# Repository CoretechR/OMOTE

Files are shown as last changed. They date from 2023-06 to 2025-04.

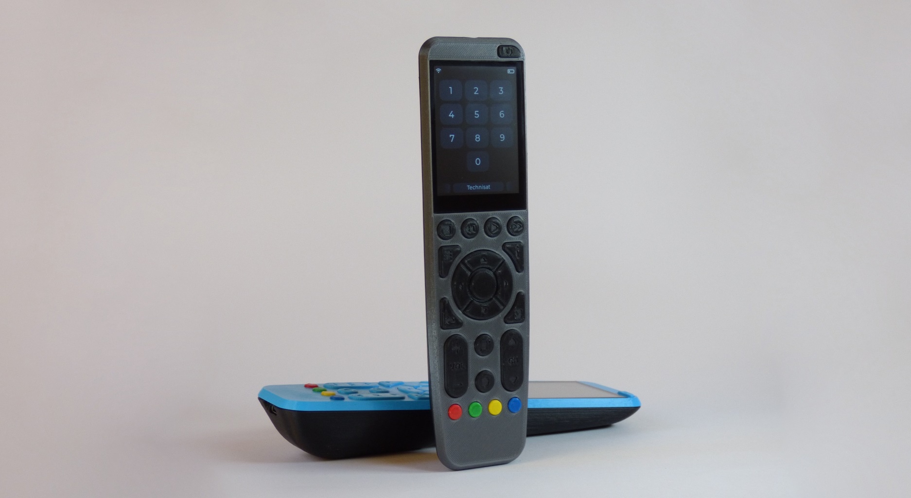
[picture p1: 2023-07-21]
images/OMOTE_assembled.jpg

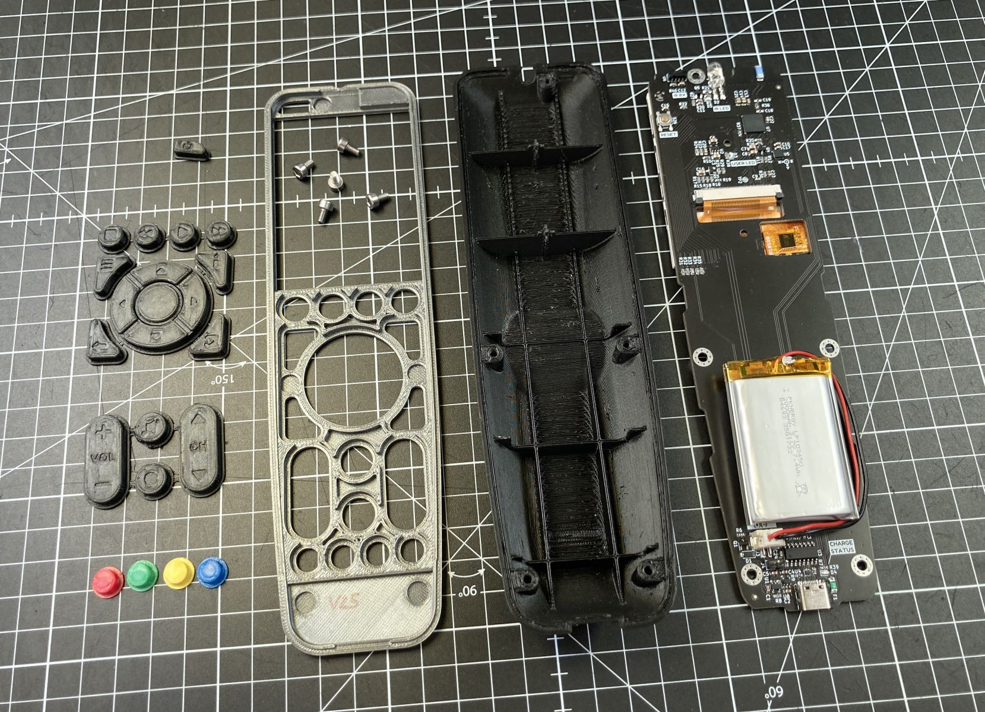
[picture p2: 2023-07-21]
images/OMOTE_parts.jpg

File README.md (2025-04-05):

# OMOTE - Open Universal Remote - Firmware




[OMOTE Discord][link1]

## Overview

This it the ESP32 arduino based firmware for the OMOTE - Open Universal Remote.

To run this firmware, you have two options
*  run it on the [OMOTE ESP32 Hardware](https://github.com/OMOTE-Community/OMOTE-Hardware/)
*  run it in the simulator on Linux, macOs or Windows

### The state of this project

The software can be adjusted to your needs. You can add your own amplifier, TV and media player. Smart home devices can be controlled with MQTT. The software is an example made up of:
* a TV and an amplifier controlled with infrared
* a Fire TV media player controlled with BLE (bluetooth keyboard)
* some smart home devices controlled with MQTT
* an IR receiver for decoding the IR codes from your remote

Please see the [wiki on how to understand and modify the firmware.](https://github.com/OMOTE-Community/OMOTE-Firmware/wiki/How-to-understand-and-modify-the-firmware)

You need to have PlatformIO running, and you need to know how to compile and flash your own firmware with PlatformIO. There is no prebuild firmware.

The remote can be charged and programmed via its USB-C port. Open the PlatformIO project to compile and upload the code to the ESP32.

As a long term goal, maybe a prebuild firmware will be published, where you can configure your OMOTE via a web interface.

### LVGL GUI simulator for Windows, Linux, and macOS

A simulator for running the LVGL UI on your local Windows, Linux, or macOS machine is available.

You can run the simulator in Visual Studio Code with PlatformIO. No need for any other compiler or development environment (no Visual Studio needed as often done in other LVGL simulators).
<div align="center">
  
</div>

For details, please see the [wiki for the software simulator for fast creating and testing of LVGL GUIs.](https://github.com/OMOTE-Community/OMOTE-Firmware/wiki/Software-simulator-for-fast-creating-and-testing-of-LVGL-GUIs)

### To Dos for software

Long term goals (not yet scheduled)
- [ ] Add an interface for graphically editing the configuration
- [ ] Store the configuration in Flash (e.g. as a editable json file)

See the [open issues](https://github.com/OMOTE-Community/OMOTE-Firmware/issues) and [discussions](https://github.com/OMOTE-Community/OMOTE-Firmware/discussions) for a full list of proposed features (and known issues).

## Contributing

If you have a suggestion for an improvement, please fork the repo and create a pull request. You can also simply open an issue or for more general feature requests, head over to the [discussions](https://github.com/OMOTE-Community/OMOTE-Firmware/discussions).

## License

Distributed under the GPL v3 License. See [LICENSE](https://github.com/OMOTE-Community/OMOTE-Firmware/blob/main/LICENSE) for more information.

## Contact

[OMOTE Discord][link1]

Join the OMOTE Discord: [https://discord.gg/5PnYFAsKsG](https://discord.gg/5PnYFAsKsG)

[link1]: https://discord.gg/5PnYFAsKsG

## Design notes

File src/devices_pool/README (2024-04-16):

This directory is intended for a pool of devices already contributed by the community of OMOTE.
Files in this directory won't get compiled by default.

If you want to use one of these devices, then
- copy the corresponding device folder from "/src/devices_pool/..." to "/src/devices/..."
- add the corresponding call to "register_device_*()" into "/src/main.cpp" (and include the device header file in "/src/main.cpp" as well)
- start using the commands defined by the device, e.g. by putting them in the hardware key map of "scene__default.cpp" or of a specific scene

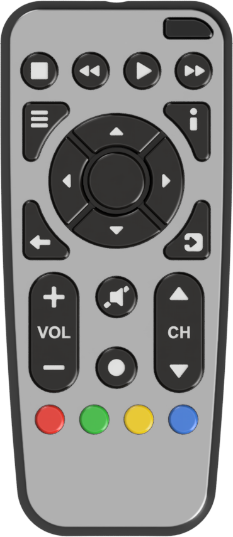
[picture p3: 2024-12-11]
hardware/windows_linux/keypad_gui/buttons.png

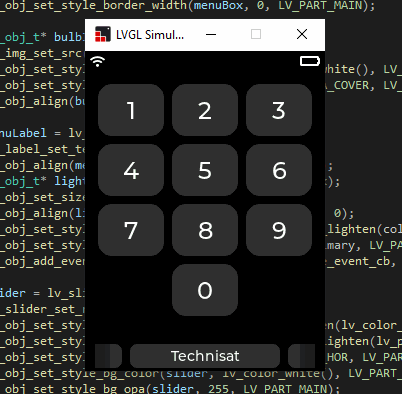
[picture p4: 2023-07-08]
images/sim GIF.gif

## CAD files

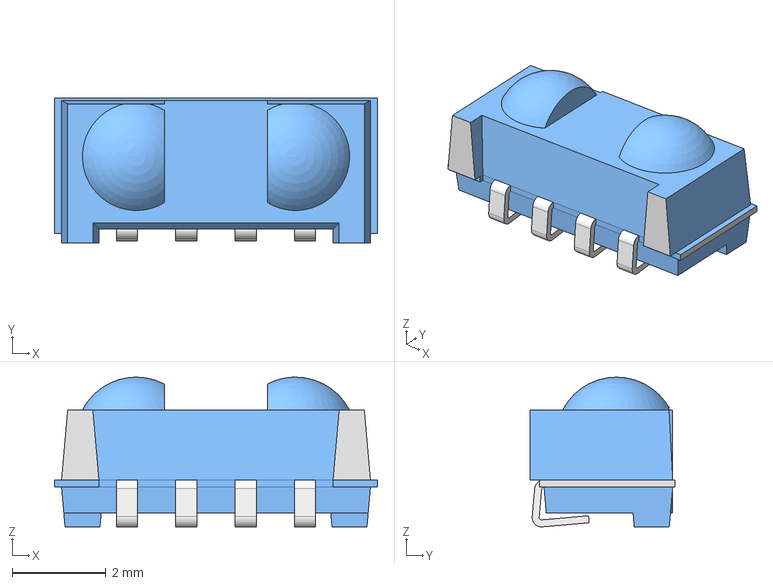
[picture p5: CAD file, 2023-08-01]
PCB/project_libraries/3D-models/82672Heimdall.stp
6.90 x 3.10 x 3.20 mm

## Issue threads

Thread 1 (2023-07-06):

Add gerber files

thijstriemstra, 2023-07-06:
Would be great to have the gerber/bom/placement files so it can be produced by a company like JLPCB or PCBWay.

I tried exporting it from Kicad 7 but there are so many options, not sure what to do, I'm new to this.

CoretechR, 2023-07-06:
Hi, you're right, I will add those files to the repository soon.
Until then there are plugins for both JLCPCB and PCBWay in KiCad that work really well.

mandreko, 2023-07-07:
I just generated these in KiCad in a way that has worked for me for previous PCBs, if it's helpful.

[OMOTE_gerber_20230707.zip](https://github.com/CoretechR/OMOTE/files/11985526/OMOTE_gerber_20230707.zip)

thijstriemstra, 2023-07-07:
thanks @mandreko. I believe we'll also need the bom and placement csv files for jlpcb (?).

CoretechR, 2023-07-08:
Added the GERBER files (7b5d897)
These were exported by the JLCPCB plugin, but should work for other manufacturers as well.

Closed 2023-07-08.

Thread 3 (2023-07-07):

BOM and sourcing components

mandreko, 2023-07-07:
Firstly, I love this project. Not just from it's sole purpose, but also for someone trying to learn electronic engineering better. I am studying the PCB to try to figure out how everything was done and the purpose of each yet.

I figured I'd start to build at least one of these. I created a BOM here: https://octopart.com/bom-tool/xXZMKVQA

The issues I have thus far, are:

1. Making sure everything on that BOM is correct.
2. Sourcing specific components that seem to be obsolete or not readily available.

Can you check that this BOM is correct, or supply one separately, to address issue 1?

For 2, I'm finding that SFH4346 is considered "obsolete" and not readily available anywhere that I can find. I think that SFH4546 might be a replacement, but I'm unsure. Additionally, trying to source the CH340C is tough as far as I can tell outside of LCSC. Is that where you got yours, or did you find it (or an alternative) elsewhere?

Thanks!

thenicnet, 2023-07-07:
Just a heads up, the **MIKROE-1120** is US Only from Mouser and DigiKey.
Anyone outside the US might have to source a comparable battery.

mandreko, 2023-07-08:
That's definitely a good note. I didn't specifically look for availability per country, but it's likely wise. I imagine there's a similar battery for other countries, but we may have to search for it some more.

CoretechR, 2023-07-08:
Hi @mandreko , I've added a BOM to the project now:
https://github.com/CoretechR/OMOTE/blob/main/PCB/BOM.csv
These are the parts that I ordered when I built the remote. Maybe you can check that against your list.
The IR LED should not be an issue. You can probably use any 3mm IR LED.

retorquere, 2023-07-09:
If anyone in Europe is looking to sell an assembled one, I'm interested.

syntaxerr66, 2023-07-12:
For those trying to source the CH340C, I just ordered some from this aliexpress vendor. Fingers crossed they're legit and work, but it was only $8 total, so it's worth a shot.

https://www.aliexpress.us/item/3256804957277020.html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

bjoerns1983, 2023-07-13:
If anyone would sell assembled PCB's i would be interested. 3D Printing is not a problem.
Love the Idea of an remote you could also use for MQTT!

moserja, 2023-07-14:
Did R1,R38,R39,R40 get removed? I don't see them in the BOM.csv file.

CoretechR, 2023-07-15:
> Did R1,R38,R39,R40 get removed? I don't see them in the BOM.csv file.

Good that you noticed, R37 was missing as well. Should be fixed now.

dekiesel, 2023-07-15:
Is there any way to subscribe to see when somebody decided to sell a ready made pcb (in the EU)? I'd love to have one of those, but my attempts at smt soldering have been very fruitless so far.

CoretechR, 2023-07-15:
@dekiesel If something comes up, I will definitely post it on Hackaday.io and Twitter.

JediMongoose, 2023-07-16:
I'd also be very interested in buying an assembled PCB.. had a look on tindie.com, but nothing yet :)

mandreko, 2023-07-16:
@JediMongoose Give it a couple weeks, and there likely will. I’ll be at least buying components for enough boards to put up there in small quantities.

JediMongoose, 2023-07-16:
> @JediMongoose Give it a couple weeks, and there likely will. I’ll be at least buying components for enough boards to put up there in small quantities. (US based)

I ended up here due to the hackaday feature (https://hackaday.com/2023/07/15/hackaday-prize-2023-omote-universal-remote/) - I'm sure there'll be more :smile:

hypercube33, 2023-07-18:
I'm doing a struggle to see if I can get PCB's made and see how impossible this is to solder myself. I've never done more than through-hole so this should be interesting. I have an immediate need for at least 2 of these, ideally expanding them with a hub when that is finalized. Also would love to help in any way! My life is a void now that Logi dropped Harmony.

mandreko, 2023-07-18:
If it’s helpful, I’ve purchased the PCBs and components for about 10x remotes. Once they come in, I’m more than happy to build some for others. I enjoy soldering.

ramonflores08, 2023-07-18:
I would do the same but don't have the funds to buy so many 😕

Dark1886, 2023-07-20:
I will also have a few boards that I will have left over, but they will not have the screen or battery installed. Those are easy additions though.

ramonflores08, 2023-07-20:
I will have 4 pcbs left over from the batch I ordered.if someone wants one and is willing to buy the components I can solder them.

Wolverine-14, 2023-07-21:
> I will have 4 pcbs left over from the batch I ordered. if someone wants one and is willing to buy the components I can solder them.

I would be interested.

tnph, 2023-07-24:
> If it’s helpful, I’ve purchased the PCBs and components for about 10x remotes. Once they come in, I’m more than happy to build some for others. I enjoy soldering.

I'm interested in buying a populated PCB, and willing to pay in advance if required

dekiesel, 2023-07-24:
It would be helpful if the people that are offering to help others would say where they are located.

GaryTill, 2023-07-24:
I'm also in Australia if anyone is selling partially or fully assembled PCBs.

demartinoj, 2023-07-25:
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

Hey! I'm located in the US and am happy to buy a pcb in whatever state it is currently in so no additional work for you. I'm happy to source and populate whatever components aren't already there.

Thanks so much! Feel free to dm me!

Amazing project by the way!!!

bjoerns1983, 2023-07-25:
Anyone has already ordered the PCB from JLCPCB?
Are there any special settings to be made, or just trhowing in the gerber.zip for PCB and Stencil and you are done?

ramonflores08, 2023-07-25:
I ordered them from jlcpcb, I should get them today.  I will let you know how it goes. I didn't add any special settings, and got the stencil as well as the pcbs.

bjoerns1983, 2023-07-25:
Great, looking forward to hear from you

mandreko, 2023-07-25:
> Anyone has already ordered the PCB from JLCPCB?
> Are there any special settings to be made, or just trhowing in the gerber.zip for PCB and Stencil and you are done?

I did nothing special. I just have them the gerber file and they look perfect. I’ll be soldering them once my last component arrives soon.
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

bjoerns1983, 2023-07-25:
Looks good.
Are there any services where you can order the other parts supplying them the BOM or  did you order every parts seperately?
Maybe letting JLCPCB solder at least one side would also be an idea.

mandreko, 2023-07-25:
I ordered from Newark, Mouser, Digikey, and one part from AliExpress (the one I’m waiting for). I used octopart to identify the cheapest part locations. I used this BOM that I made from the official BOM: https://octopart.com/bom-tool/xXZMKVQA

Dark1886, 2023-07-25:
Single sided soldering at JLCPCB could be pretty good guidance for most since it allows for many of the small components to be added and only requiring the buttons to be soldered on later. Although I noticed when I entered my parts into JLCPCB that many of the parts didn't have the correct orientation or placement, so you need to be very careful before ordering.
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
dekiesel, 2023-09-05:
> Anyone found reliable place in EU to make those PCBs?

PCBWay sends to the EU. I haven't ordered this pcb from them, but others, and always without issues.

gacekk, 2023-09-05:
> > Anyone found reliable place in EU to make those PCBs?
>
> PCBWay sends to the EU. I haven't ordered this pcb from them, but others, and always without issues.

Thanks

I guess the gerber.zip under production folder is the one to use?

gacekk, 2023-09-06:
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

Would you mind sharing your order number so I can reference it in case they come back to me with questions?

tnph, 2023-09-06:
Sure, my order number was G1087248 and I previously posted the BOM spreadsheet including part substitutions. Cheers

gacekk, 2023-09-06:
Tha

> Sure, my order number was G1087248 and I previously posted the BOM spreadsheet including part substitutions. Cheers

Thank you kind sir. They already reviewed my PCB and are reviewing assembly now. Will see if they get back to me with sth

gacekk, 2023-09-08:
> Sure, my order number was G1087248 and I previously posted the BOM spreadsheet including part substitutions. Cheers

For some reason they are now saying our orders differ to make adjustments to mine based off yours. I just asked if they can simply copy yours. If you know that yours is working

tnph, 2023-09-08:
I had a to substitute a few parts so maybe that's why. But mine works fine
so no risk using the parts in my spreadsheet

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

gacekk, 2023-09-08:
Thanks for confirming

mailuminatti, 2023-09-17:
Not sure how many people would be interested, but how crazy would it be to order a "bulk" of populated PCBs and have them distributed? Man, I have way too many remotes.

Dark1886, 2023-09-18:
I also have additional pcbs, but I won't be shipping any out until pros October-November at the earliest. If anybody would like one, just let me know.

dekiesel, 2023-09-18:
@Dark1886, I am interested, but where are you located?

Dark1886, 2023-09-18:
> @Dark1886, I am interested, but where are you located?

I'm located in the US.

truckershitch, 2023-09-18:
@Dark1886 Hey Blake, I am also interested.  I'm also in the US.

Dark1886, 2023-09-18:
For all those interested, Please go to the discord. I will put a thread in the Buy/Sell page and it will be easier to track.

gacekk, 2023-09-29:
So my PCB came without screen and battery. Anyone can suggest any nice screens from AliExpress that will suit the housing. Battery as well?

tnph, 2023-09-30:
> So my PCB came without screen and battery. Anyone can suggest any nice screens from AliExpress that will suit the housing. Battery as well?

I'm not sure where you're located but for reference I bought these from Little Bird Electronics and they fit perfectly.
1 Lithium Ion Battery - 3.7v 2000mAh . Partno:  AF-2011
1 2.8" TFT Display - 240x320 with Capacitive Touchscreen. Partno: AF-2770

gacekk, 2023-09-30:
To all interested the display appears to be Adafruit 1774

CoretechR, 2023-09-30:
@gacekk Hi, sorry for commenting so late. The display is not the Adafruit 1774 but the 2770. The difference is in the touchscreen, 1774  is resistive, only 2770 is capacitive. The OMOTE board is not compatible with the resistive screen. You can find details in the BOM file:
https://github.com/CoretechR/OMOTE/blob/main/PCB/BOM.csv
Sourcing the battery depends on where you live.

gacekk, 2023-09-30:
> @gacekk Hi, sorry for commenting so late. The display is not the Adafruit 1774 but the 2770. The difference is in the touchscreen, 1774 is resistive, only 2770 is capacitive. The OMOTE board is not compatible with the resistive screen. You can find details in the BOM file: https://github.com/CoretechR/OMOTE/blob/main/PCB/BOM.csv Sourcing the battery depends on where you live.

Great. Thanks for correcting me. Somehow batteries seem to be more tricky. Will need to dig more on AliExpress for battery

huenemeca, 2023-10-25:
> I also have additional pcbs, but I won't be shipping any out until pros October-November at the earliest. If anybody would like one, just let me know.

@Dark1886 I am also interested.  If you still have any.  I am in California.

Dark1886, 2023-10-26:
> > I also have additional pcbs, but I won't be shipping any out until pros October-November at the earliest. If anybody would like one, just let me know.
>
> @Dark1886 I am also interested. If you still have any. I am in California.

Unfortunately
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

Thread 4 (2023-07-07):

Fredoka Light font missing

mandreko, 2023-07-07:
When I initially open the PCB designer, I get a message that the Fredoka Light font is missing, since it's not a system font. I'm not sure if it's super important to have that specific font, but if so, it might make sense to include it in the repository and reference it.

CoretechR, 2023-07-08:
Solved in 0784a3b
I created most of the labels with the KiBuzzard Plugin except for the XYZ letters near the accelerometer. These are switched over to KiBuzzard as well now so you do not need the Fredoka font anymore.

Closed 2023-07-08.

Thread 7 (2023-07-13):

OMOTE Rev3.pdf cannot be opened

Insomniac80, 2023-07-13:
Hiho,

[OMOTE Rev3.pdf](https://github.com/CoretechR/OMOTE/blob/main/PCB/OMOTE%20Rev3.pdf) seems to be broken.

Best regards

CoretechR, 2023-07-14:
Hi, what software are sou using? It works fine for me with the browser and Acrobat.

riker09, 2023-07-14:
I can open and view it on my Android as well

Closed 2023-07-17.

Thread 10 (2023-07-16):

IR learning abilities

Jonas-fr, 2023-07-16:
Would you consider adding an IR-receiver to allow IR-learning abilities (via a future firmware update) to this remote? It will vastly expand the use-cases for it.

Jonas-fr, 2023-07-17:
This modular approach is sound! Do you have more details about such an external IR receiver and where it could be plugged in on the current remote?

riker09, 2023-07-17:
Not sure if it can be helpful here, but there is Flipper, a hacker tool similar to this project that allows reading IR codes (and replay them).

CoretechR, 2023-07-17:
There's an IR receiver built into the remote already (U6). Learning codes is currently not used in the software, but I have tested that the sensor works.

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

Jonas-fr, 2023-07-17:
> Not sure if it can be helpful here, but there is [Flipper Zero](https://flipperzero.one/), a hacker tool similar to this project that allows reading IR codes (and replay them).

I know very well about it but it's too expensive just for one use case (IR learning).

> There's an IR receiver built into the remote already (U6). Learning codes is currently not used in the software, but I have tested that the sensor works.
>
> 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

My bad, I didn't saw it along with IR LEDS. Well this is perfect ! Would you be open to future PR regarding IR learning functions then or do you want to focus on the TX side for now?

CoretechR, 2023-07-17:
I can't promise anything right now.
Honestly I wanted to take a break from this project as I have put too much time into it already.
But since so many people seem interested, I might have to keep working on it.

For my previous [OLED keyboard project](https://github.com/CoretechR/Keybon), I created a windows UI for configuring the screens. I imagine something similar could be done with the remote. A web interface hosted on the ESP32 would make it cross-platform, but I'm not sure about the performance. The IR learning would be part of that interface.

Jonas-fr, 2023-07-17:
You don't have to promise anything, you can (should!) take a break whenever you like! I was just asking if that (RX abilities) would be a direction you'd like for this project in the short/middle term or not.

Anyway thank you for all the work you've already put into this project!

Dark1886, 2023-07-19:
Just adding an idea that could help with IR command learning, could the commands be added into the eeprom locations to allow dynamic changing without needing to hardcode into the values in the source code. I'm hoping to work on this when I can get my hands on the parts.

CoretechR, 2023-07-19:
@Dark1886 Sure, the flash memory of the ESP32 would be the best place to store the commands. You're welcome to try an implement this.

Dark1886, 2023-08-02:
Just a thought, If adding IR learning functionality on-board may be difficult, an IR reading mode could be implemented that could spit out the received IR signal to some serial/http Post/MQTT log. It doesn't directly learn the function, but it could make capturing and programming the IR codes a lot more simple.

KlausMu, 2024-01-17:
I implemented an IR receiver, looks like this:
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

Even recognizes the codes which the OMOTE is sending by itself :-)

I can publish this later. But currently I'm still working on some other features.
I'm afraid my IR receiver code can not be provided as a pull request to the original source file. I did more or less a complete rewrite.
I used a more modular approach, with separation of code into devices (describing their abilities), the gui parts (single files for each device), the user interfaces (keypad, touch), and a command pattern for sending and receiving commands like INCREASE_VOLUME, beside some other stuff.
Overall more than 40 (small) files. But (at least to me) much better understandable and customizable than a single file with >1000 lines.
Still need some time to finish it. So stay tuned ...

Closed 2025-04-06.

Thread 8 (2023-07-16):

BOM Fixes

mandreko, 2023-07-16:
You previously went through and added the BOM in #3 but I found a couple minor discrepancies when looking at parts today:

1. R1; R38; R39; R40 has a quantity of "2" listed, when it should be "4"
2. R6; R11; R12; R13; R14; R19; R20; R22; R26; R30; R31; R32; R33; R34; R35; R37 has a quantity of "15" listed, when it should be "16"
3. J4 is missing. It looks to be just a standard pin header that most people building this probably have sitting around, but for "completeness", it should probably be added

CoretechR, 2023-07-17:
I missed that, thank you! The pin header is really just for measuring current consumption by suppling the board from an external power supply.

Closed 2023-07-17.

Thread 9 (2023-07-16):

Would data from the Logitech Harmony API be helpful for development?

TheFiZi, 2023-07-16:
I'm a long time Harmony user and this remote looks like an awesome alternative for when my Harmony inevitably stops working.

I saw in the write up that device support is currently limited and you're hoping to develop an application with, I assume, similar functionality to how the Logitech Harmony App works for programming a remote.

I did some digging today in the MyHarmony App for iOS and was able to pull some data from the Logitech API by searching for a random device, a Denon AVR-A1, just to see what I could get.

Attached is the JSON output:

[jsonExport1.txt](https://github.com/CoretechR/OMOTE/files/12065128/jsonExport1.txt)
[jsonExport2.txt](https://github.com/CoretechR/OMOTE/files/12065129/jsonExport2.txt)

I did a quick skim of the data and I can't see anything that jumps out to me as IR codes that could be helpful.

I guess my question is: Is this data at all useful? and would you like more if I could figure out how to get more?

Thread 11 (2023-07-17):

hub option

TomW1605, 2023-07-17:
someone sent me a link to this project and it looks really cool, i was considering doing it myself when my harmony remote dies but i hope i wont need to.

one thing though, it mentiones not needing a hub as a good thing but i think there a quite a few functions that a hub provides that make having one a good thing. in particular it allows for your av devices to be controlled through an app, webpage or automation system wihtout worrying about where the remote is and if its pointed at the devices. it also allows the remote to control devices that may be hidden without needing an IR repeater setup.

while i do think not *needing* one is good it would be great to have the option of adding one. i dont know if it would be best to try and add a direct RF connection to a hub or just rely on them both connecting to wifi but i think having a hub of some form is great.

same goes for a dock, having contacts exposed on the case and a dock that just has 5v on a pair of pogo pins would be a great addition to eliminate the need to activly charge the remote at all

either way i love this project and will be following it with great intrest. and would be happy to have a stab at a hub to go with this if you would be intrested

Dark1886, 2023-07-17:
I think having a hub feature may be nice, but I suspect that would be a bit down the road since I think there are other more important features currently needed. Although I think a hub could be used if you essentially took main MCU and used that as a hub with only a basic "client" remote that is just guiding the main hub.

As usual with open source projects, feel free to take a stab at it since that is what will generally push the 'experiment' closer to a real feature in the project.

TomW1605, 2023-07-18:
i agree there are more important things, i really just wanted to raise it so it wasnt outright discounted as an option.

i think the hub as main with a client remote (that probably just has RF and maybe IR) is how the harmony hub bassed remotes worked but in this case i think having it as an addon so it works with the OMOTE without changing the OMOTE would work better since it means you can save that cost if you dont need it.

ill take a stab at a pcb design at some point and report back if i get anywhere

CoretechR, 2023-07-18:
@TomW1605 A hub as an optional add-on is a nice idea. Many smart remotes completely rely on a hub for communication and power, so I wanted to set my remote apart from that. But there are obvious advantages, like better IR range without having to point the remote at the device you want to control. If you want to try and make a ESP32 hub, that would be great, not just for this project alone.

hypercube33, 2023-07-18:
+1 on the hub. I agree that a hub piece for this is something I was hoping for. The project is absolutely awesome, and I intend to try to figure out how to make it since I depend on my Harmony Remote + Hub daily on all our media systems. The hub could be an ESP8266 or ESP32 running an IR blaster that the remote can send commands to output. I think there are other projects that do serial over wifi to ESP's - why this matters is because it integrates nicely with home assistant and other automations and the remote may not have line of sight to some devices which makes using it for IR annoying - the hub we have sits in a cabinet closed away but still controls IR devices nicely.

Dark1886, 2023-07-18:
@hypercube33 If you plan to design some sort of hub, it could be possible to just use the Bluetooth LE or just the LAN to connect the two, then you wouldn't require a direct line-of-sight to the hub itself.

GaryTill, 2023-07-26:
Any of the dozens of existing generic ESP based IR hubs can be easily loaded with pre-made firmware from ESPhome or Tasmota to subscribe to MQTT and blast out IR very simply.

Then it's just a matter of having some functions on the remote mapped to MQTT on a per device/room/etc basis. The IR commands could be hard coded into the remote, or it could be handled externally by nodered or similar for flexibility and smarter handling the commands without having to hardcode everything.

I mostly use direct IR in my current setup (I already have an IR distribution rig as part of the video matrix setup), I do use broadlink emitters for automation of air conditioning and such, so they can be useful, particularly for whole home control from one remote.

TomW1605, 2023-07-26:
yes hubs like that would work but i would probably want to write new code that more directly interacts with the remote.

also i think if we were to design one from scratch we could/shoud add 3.5mm jacks to have remote ir leds like many ir repeater systems use. that way you wouldent need to try and put the hub where it can see all the devices or need a seprate repeater system

Dark1886, 2023-08-07:
I think the hub will be a good idea, But I assume that will not be a main priority since the software will likely be in flux for a while, so adding additional complexity will not be priority.

Closed 2025-04-06.

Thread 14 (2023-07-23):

Can't build simulator

MatthewColvin, 2023-07-23:
Hey @CoretechR I am super interested in contributing to this project. But currently when I open the simulator project it will not build.

I was wondering if you considered forking the simulator repo and then adding it to this project as a submodule?

I could also help set up some GitHub actions to get build validation.

CoretechR, 2023-07-23:
Hi @MatthewColvin, did you set the target in Visual Studio to x64? It might [be set to ARM64](https://github.com/lvgl/lv_port_pc_visual_studio#known-issues) by default.
I'm not very proficient with GitHub so I just copy-pasted the simulator project in there. A proper fork might be better, I will look into it.
And thank you, any contributions are welcome! Do build validations work with embedded projects like this?

MatthewColvin, 2023-07-23:
I am set to target the x64 build. And yeah we can set up build validation for the platformio project along with the simulator.

I am unsure how those interact with one another at this point but I look forward to digging in.

Let me get the compiler error and paste it in here

MatthewColvin, 2023-07-23:
Error	C1083	Cannot open source file: 'C:\Users\mcolv\Desktop\OMOTE\LVGL Simulator\LvglPlatform\lvgl\examples\widgets\obj\lv_example_obj_2.c': No such file or directory

CoretechR, 2023-07-23:
The entire obj folder inside OMOTE\LVGL Simulator\LvglPlatform\lvgl\examples\widgets is missing.
It's there on my machine but GitHub for Desktop does not recognize it so it was never committed.
There is no gitignore file that would make GitHub ignore this folder. Do you have any idea what would cause this?

MatthewColvin, 2023-07-23:
Yeah this is a sub module inside the other repo can you tell me the commit SHA of the LVGL Simulator you are using?

I can fork it and then pull it into the OMOTE repo as a submodule.

CoretechR, 2023-07-23:
It took some convincing but the missing files are online now (53f9d1b).
I will try and switch to a proper submodule.

> I am unsure how those interact with one another at this point but I look forward to digging in.

The simulator and the Platformio projects don't have any direct connection at the moment. I just carefully copy the code between them. It's not very elegant, but it works. There are just too many differences to make these 1:1 compatible.

MatthewColvin, 2023-07-23:
thanks for pulling in those files. This is so sweet!!!

> The simulator and the Platformio projects don't have any direct connection at the moment. I just carefully copy the code between them. It's not very elegant, but it works. There are just too many differences to make these 1:1 compatible.

Is there something you would like me to try and implement? or I can look into the easiest way to share code between the sim and the HW?

CoretechR, 2023-07-23:
If you want to, sure. Linking the simulator to the embedded code would be nice, but its not really crucial for the further development.
I don't have any concrete plans on what to do next with this project, but I'd like to make the existing functionality as stable as possible for the people that are building their boards. After that, the next big step would be adding some kind of customization to the UI.

Dark1886, 2023-07-28:
There are other projects that use Platformio to simulate the LVGL screen, although I'm not sure if that really allows for editing of the display in any easy way. I'm intending to look a theses when I have some time, but I haven't had as much time as I'd like recently. I admit I'm also not familiar with LVGL so maybe others would have more information.

Information collection:
https://blog.drorgluska.com/2022/07/lvgl-esp32-and-desktop-development.html
https://github.com/lvgl/lv_platformio

Closed 2023-07-23.

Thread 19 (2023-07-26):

Some parts models are missing from the kicad project

Dark1886, 2023-07-26:
Some of the footprints/models for components are pointing to a /mkern/ library that does not seem to be stock in the kicad application. If these are custom footprints, can those models be shared?

CoretechR, 2023-07-26:
Hi, these are custom made footprints. I can add them to the repository when I get back to my PC.
The footprints should also be included in the KiCad pcb file, they are just not directly accessible.

Dark1886, 2023-08-01:
@CoretechR Just pinging you again in case you forgot. I'd like to try and update some of the footprints and create a package that will be more easily 'drag-and-drop'ed into JLCPCB or PCBWay without needing to do additional part orientation/placement updates.

CoretechR, 2023-08-01:
@Dark1886 I am still new to KiCad so it took a while :)
The missing files are now inside "omoteLib" as a project-specific library.
Maybe you can check if everything's accounted for.

Dark1886, 2023-08-01:
No Problem, I'll take a look at that in the near future.

CoretechR, 2023-09-17:
@Dark1886 Did you have time to look at the footprints?

Dark1886, 2023-09-18:
I did load the files you added as custom parts and it did load in correctly.

Closed 2023-11-10.

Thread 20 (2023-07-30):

i2cRead Error on newly made board

Dark1886, 2023-07-30:
I just got my board together and i'm seeing the following problem rather frequently, but i'm not entirely sure how to track down what is causing it yet.
`[133754][E][Wire.cpp:513] requestFrom(): i2cRead returned Error 263`

My screen appears to be working, but I'm thinking this is going to cause a headache if I don't figure it out now.

EDIT: This may have just been because I didn't have the display taped down yet and any movement was causing an SPI error. I will tape it down and hope no more errors happen.

Closed 2023-07-30.

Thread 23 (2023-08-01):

Find a to way to compile Arduino targeting windows

MatthewColvin, 2023-08-01:
This would allow us to put Arduino library dependencies in the OmoteUI.hpp which would be really nice.

Dark1886, 2023-08-01:
Can you explain the exact issue here? I would like to assist but seem a little confused about the actual problem.

MatthewColvin, 2023-08-06:
I don't think this original ticket was feasible but this accomplishes a similar task.

Thanks to @Dark1886 for pointing me to https://github.com/lvgl/lv_platformio I have an extremely rough version of the simulator working in platform IO so hopefully we can ditch the solution after we get it properly added :)

CC: @CoretechR

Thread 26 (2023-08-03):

Serial Upload error on previously good board.

Dark1886, 2023-08-03:
I'm having issues uploading to my board. I had previously uploaded without issues. I thought maybe I did something to my board and fried it, but another board that I haven't tinkered with also is having the same behavior. From my initial investigation it seems the automatic bootloader reset is not working as expected, but that could be a wrong assumption.

Any ideas why this could be happening?

```
Verbose mode can be enabled via `-v, --verbose` option
CONFIGURATION: https://docs.platformio.org/page/boards/espressif32/esp32dev.html
PLATFORM: Espressif 32 (6.1.0) > Espressif ESP32 Dev Module
HARDWARE: ESP32 240MHz, 320KB RAM, 4MB Flash
DEBUG: Current (cmsis-dap) External (cmsis-dap, esp-bridge, esp-prog, iot-bus-jtag, jlink, minimodule, olimex-arm-usb-ocd, olimex-arm-usb-ocd-h, olimex-arm-usb-tiny-h, olimex-jtag-tiny, tumpa)
PACKAGES:
 - framework-arduinoespressif32 @ 3.20007.0 (2.0.7)
 - tool-esptoolpy @ 1.40500.0 (4.5.0)
 - tool-mkfatfs @ 2.0.1
 - tool-mklittlefs @ 1.203.210628 (2.3)
 - tool-mkspiffs @ 2.230.0 (2.30)
 - toolchain-xtensa-esp32 @ 8.4.0+2021r2-patch5
LDF: Library Dependency Finder -> https://bit.ly/configure-pio-ldf
LDF Modes: Finder ~ chain, Compatibility ~ soft
Found 45 compatible libraries
Scanning dependencies...
Dependency Graph
|-- SparkFun LIS3DH Arduino Library @ 1.0.3
|-- IRremoteESP8266 @ 2.8.6
|-- Adafruit FT6206 Library @ 1.0.6
|-- lvgl @ 8.3.7
|-- TFT_eSPI @ 2.5.31
|-- PubSubClient @ 2.8.0
|-- WiFi @ 2.0.0
|-- Wire @ 2.0.0
|-- Keypad @ 3.1.1
|-- Preferences @ 2.0.0
Building in release mode
Retrieving maximum program size .pio\build\esp32\firmware.elf
Checking size .pio\build\esp32\firmware.elf
Advanced Memory Usage is available via "PlatformIO Home > Project Inspect"
RAM:   [===       ]  34.2% (used 111904 bytes from 327680 bytes)
Flash: [========  ]  84.6% (used 1108533 bytes from 1310720 bytes)
Configuring upload protocol...
AVAILABLE: cmsis-dap, esp-bridge, esp-prog, espota, esptool, iot-bus-jtag, jlink, minimodule, olimex-arm-usb-ocd, olimex-arm-usb-ocd-h, olimex-arm-usb-tiny-h, olimex-jtag-tiny, tumpa
CURRENT: upload_protocol = esptool
Looking for upload port...
Using manually specified: COM9
Uploading .pio\build\esp32\firmware.bin
esptool.py v4.5
Serial port COM9
Connecting......................................

A fatal error occurred: Failed to connect to ESP32: Invalid head of packet (0x5B): Possible serial noise or corruption.
For troubleshooting steps visit: https://docs.espressif.com/projects/esptool/en/latest/troubleshooting.html
*** [upload] Error 2
```

Dark1886, 2023-08-03:
Closing this. It currently appears that a USB port on my PC could not supply enough power for a stable upload. Manually holding GPIO0 low did fix this problem, but is a bad solution for multiple reasons.

If you experience this issue yoou may be able to do one of the following.
1. Different USB port, especially a motherboard USB port and not a front panel port.
2. A powered USB Hub
3. a Y splitter to plug your device into two separate ports on your PC. (I do not recommend this, but it is an option).

GaryTill, 2023-08-03:
That's an interesting one.. what is the default charge current on the battery controller, I haven't actually checked.
If it's 500ma then there is a chance this will happen occasionally on standard 500ma ports with some USB computers.

Seems like a minor issue thankfully.

CoretechR, 2023-08-03:
@GaryTill the charge current is set to 333mA so that should be ok. But then you have the normal power consumption of the board on top. I have found that the real USB power draw is still pretty low with less than 400mA. Still it might be better to power the ESP from the battery instead from USB, instead of prioritising USB.

@Dark1886 Do you have any way to measure the USB current with your board?

Dark1886, 2023-08-03:
@CoretechR I do have a USB power meter laying around somewhere and I can test it with that. I'm not sure if it's necessarily the overall power draw that is causing the problem, but it may have just been the transient spikes from boot-up. I'll take a look at it tonight if I can find the meter.

KlausMu, 2023-12-13:
I have the same problem. No upload is possible, no matter which USB cable I use (short, thick, high quality) and which USB port (mainboard, front panel, powered USB hub).
I always have to pull down GPIO0 manually. I do it by connecting R37 to GND (of the USB port).
Any better solution or workaround?

Dark1886, 2023-12-13:
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

Unfortunately I have yet to find a different solution, but a powered hub or a different USB port fixes my problems so I didn't continue searching.

I believe uploading from a Linux machine could be helpful as it handles the serial communication differently.

KlausMu, 2023-12-18:
> I believe uploading from a Linux machine could be helpful as it handles the serial communication differently.

Indeed, uploading from the same machine, but using WSL2, worked. Strange ...

Dark1886, 2023-12-18:
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

Wow, I didn't think WSL2 Would actually work for that. But glad to hear although it is unfortunate.

Closed 2023-08-03.

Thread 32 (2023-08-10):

R21 seems to have wrong value

Salecorp, 2023-08-10:
It seems like 3R3 is too low for protecting the IR LED.
Is this a mistake or on purpose?

CoretechR, 2023-08-10:
The small resistor is an intentional choice to get the best possible range out of the LED. Most 5mm IR LEDs are specified for a pulse current of around 1A. The LED is controlled by the IR library so it should be fine. But if a programming error occurs and the LED is powered on for more than a few milliseconds, it will get damaged. Some kind of protection circuit would be part of the next hardware revision.

Salecorp, 2023-08-10:
I see, thank you for the clarification!

samdowrick, 2023-08-10:
@CoretechR
Here's an approach that utilizes the 555 timer for protection:

1. Connect +3.3V Supply to 555 Timer:
        Connect the +3.3V supply to the power input of the 555 timer.
2.Configure 555 Timer as One-Shot:
        Set up the 555 timer in monostable mode to generate a pulse when triggered.
3.Trigger 555 Timer:
        Connect the trigger input of the 555 timer to the microcontroller's output. The microcontroller will trigger the 555 timer to
        start its timing cycle.
5. Connect 555 Timer Output to Transistor Base:
        Connect the output of the 555 timer to the base of an NPN transistor (e.g., 2N2222 or similar).
6. Connect Transistor Collector to +3.3V:
        Connect the collector of the transistor to the +3.3V supply.
7. Connect Transistor Emitter to Q5 (DMG2301L):
        Connect the emitter of the transistor to the source pin (pin2) of the DMG2301L mosfet.
Rest of the circuit remains unchanged.

I can modify the schematic and upload an image to show this if it doesn't make sense.

CoretechR, 2023-08-11:
@samdowrick Your idea makes perfect sense. I was actually considering using a resettable fuse or a big capacitor to limit the energy to the LED. But yours is a much more clever solution. Thank you!
I've added it to the list of suggestions for a new hardware revision: https://github.com/CoretechR/OMOTE/discussions/24

CoretechR, 2023-08-16:
Fixed in commit #33

Closed 2023-08-16.

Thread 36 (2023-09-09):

There is a certain probability of restarting ESP32 several times during startup

vihor3, 2023-09-09:
```
[    15][D][esp32-hal-cpu.c:244] setCpuFrequencyMhz(): PLL: 480 / 2 = 240 Mhz, APB: 80000000 Hz
[   440][I][esp32-hal-i2c.c:75] i2cInit(): Initialising I2C Master: sda=19 scl=22 freq=400000
[   441][W][Wire.cpp:301] begin(): Bus already started in Master Mode.
[   568][D][WiFiGeneric.cpp:1035] _eventCallback(): Arduino Event: 0 - WIFI_READY

Brownout detector was triggered
```
The UART output is like this, sometimes this segment will repeat 4-5 times, sometimes 1-2 times, and then the screen will light up normally

MiniJe, 2023-09-09:
This is a power problem. You need a more capable power supply to feed the
ESP32. If using a USB-powered dev board, try replacing the USB cable and
connecting it directly to a USB port on your computer. A powered USB hub
might also help.
Also, you can add   WRITE_PERI_REG(RTC_CNTL_BROWN_OUT_REG, 0); //disable
brownout detector

void printBootReason()
{
    esp_reset_reason_t reset_reason = esp_reset_reason();

    switch (reset_reason)
    {
    case ESP_RST_UNKNOWN:    Serial.println("Reset reason can not be
determined"); break;
    case ESP_RST_POWERON:    Serial.println("Reset due to power-on
event"); break;
    case ESP_RST_EXT:        Serial.println("Reset by external pin
(not applicable for ESP32)"); break;
    case ESP_RST_SW:         Serial.println("Software reset via
esp_restart"); break;
    case ESP_RST_PANIC:      Serial.println("Software reset due to
exception/panic"); break;
    case ESP_RST_INT_WDT:    Serial.println("Reset (software or
hardware) due to interrupt watchdog"); break;
    case ESP_RST_TASK_WDT:   Serial.println("Reset due to task
watchdog"); break;
    case ESP_RST_WDT:        Serial.println("Reset due to other
watchdogs"); break;
    case ESP_RST_DEEPSLEEP:  Serial.println("Reset after exiting deep
sleep mode"); break;
    case ESP_RST_BROWNOUT:   Serial.println("Brownout reset (software
or hardware)"); break;
    case ESP_RST_SDIO:       Serial.println("Reset over SDIO"); break;
    }

    if (reset_reason == ESP_RST_DEEPSLEEP)
    {
        esp_sleep_wakeup_cause_t wakeup_reason = esp_sleep_get_wakeup_cause();

        switch(wakeup_reason)
        {
            case ESP_SLEEP_WAKEUP_UNDEFINED:    Serial.println("In
case of deep sleep: reset was not caused by exit from deep sleep");
break;
            case ESP_SLEEP_WAKEUP_ALL:          Serial.println("Not a
wakeup cause: used to disable all wakeup sources with
esp_sleep_disable_wakeup_source"); break;
            case ESP_SLEEP_WAKEUP_EXT0:         Serial.println("Wakeup
caused by external signal using RTC_IO"); break;
            case ESP_SLEEP_WAKEUP_EXT1:         Serial.println("Wakeup
caused by external signal using RTC_CNTL"); break;
            case ESP_SLEEP_WAKEUP_TIMER:        Serial.println("Wakeup
caused by timer"); break;
            case ESP_SLEEP_WAKEUP_TOUCHPAD:     Serial.println("Wakeup
caused by touchpad"); break;
            case ESP_SLEEP_WAKEUP_ULP:          Serial.println("Wakeup
caused by ULP program"); break;
            case ESP_SLEEP_WAKEUP_GPIO:         Serial.println("Wakeup
caused by GPIO (light sleep only)"); break;
            case ESP_SLEEP_WAKEUP_UART:         Serial.println("Wakeup
caused by UART (light sleep only)"); break;
        }
    }
}

În sâm., 9 sept. 2023 la 05:00, vihor3 ***@***.***> a scris:

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

vihor3, 2023-09-09:
Thank you. I have redrawn the PCB for this project and used HT7833's LDO, which may not be able to handle situations where WiFi and screen backlight are turned on simultaneously. I am going to try replacing the ME6211 for testing. This LDO has better dynamic response, but its static power consumption is a bit high. Perhaps it is also possible to try increasing the capacitance of the input and output capacitors to solve the problem

MiniJe, 2023-09-09:
Suggestion for measuring battery level:
How to measure battery level with ESP32 microcontroller | Andrey Ovcharov
<https://en.ovcharov.me/2020/02/29/how-to-measure-battery-level-with-esp32-microcontroller/>

All the best
Pau

În sâm., 9 sept. 2023 la 11:20, vihor3 ***@***.***> a scris:

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

vihor3, 2023-09-09:
For this project, ESP32-Pico-D4 no longer has more IO to use, so the functions in the article cannot be implemented unless ESP32-S3 is replaced

MiniJe, 2023-09-09:
you can use LCD_EN ...
the function for measuring the battery level should only be activated when
the remote control is at rest (placed) and the LCD is with the backlight off

În sâm., 9 sept. 2023 la 11:43, vihor3 ***@***.***> a scris:

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

CoretechR, 2023-09-09:
Is there a problem with the existing battery measurement? It's only a simple voltage divider but it works for me and has a very low power draw.

MiniJe, 2023-09-09:
Unfortunately the version with the divider is not stable. plus it
discharges the battery faster because the divider acts as a load.

There are many issues discussed on the forums, related to measuring the
level in the battery.
https://esp32.com/viewtopic.php?t=29582
https://forum.arduino.cc/t/fixing-the-non-linear-adc-of-an-esp32/699190
.. and other examples.
I use: https://eu.mouser.com/datasheet/2/609/MAX17300_MAX17313-3127492.pdf
In addition, your project is 5 stars. The above observations are from
personal experience and are intended to increase operational reliability

În sâm., 9 sept. 2023 la 12:19, Max K ***@***.***> a scris:

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

CoretechR, 2023-09-09:
The ADC of the ESP32 is notoriously bad and non-linear. The 600kOhm voltage divider uses 6uA, so it can give a rough estimate of the battery state. A fuel gauge like you suggested, is a much nicer solution. I would definitely consider this for a new hardware revision.

vihor3, 2023-09-09:
It is said that the ADC input impedance of ESP32 is less than 100K, so it is best to use a divider resistor that is less than 100K. However, reducing the resistance value will lead to an increase in power consumption. My solution for this is to use a P-MOS to control the BATT access to the voltage divider network. Of course, the IO of ESP32-Pico-D4 is currently insufficient, and the FLASH storage footprint seems to be full. Therefore, I suggest replacing it with a more powerful ESP32-S3 and supporting a larger FLASH IC

vihor3, 2023-09-09:
Of course, such changes will incur additional costs. If there are no special requirements, the current hardware is already sufficient to use, and the next work only needs to optimize the software

Closed 2023-09-10.

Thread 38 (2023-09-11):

MQTT Support on Abstraction Branch

MatthewColvin, 2023-09-11:
When abstracting out wifi and other HW component MQTT support dropped off so need to add it back.

baerrs, 2024-03-04:
I've got the MQTT working (not the Keyboard).

Before this, it would cause the WiFi to disconnect after the first MQTT publish. Sometimes the WiFi would recover, sometimes it wouldn't.
Looking at the MQTT Server logs, it appeared that OMOTE was connecting as OMOTE, and then multiple different ClientID's.

These changes stopped that.
I had to disable the Keyboard.  I commented out all entries in
I don't know if I had to do all this.. but it is working after i did.
```
void register_device_keyboard_mqtt() {
  // commands[KEYBOARD_MQTT_UP]                   = makeCommandData(MQTT, {"esp32_keyboard_firetv/cmnd/UP",                  "PRESS"});
  // commands[KEYBOARD_MQTT_DOWN]                 = makeCommandData(MQTT, {"esp32_keyboard_firetv/cmnd/DOWN",                "PRESS"});
  // commands[KEYBOARD_MQTT_RIGHT]                = makeCommandData(MQTT, {"esp32_keyboard_firetv/cmnd/RIGHT",               "PRESS"});
  // commands[KEYBOARD_MQTT_LEFT]                 = makeCommandData(MQTT, {"esp32_keyboard_firetv/cmnd/LEFT",                "PRESS"});
  // commands[KEYBOARD_MQTT_SELECT]               = makeCommandData(MQTT, {"esp32_keyboard_firetv/cmnd/SELECT",              "PRESS"});
  // commands[KEYBOARD_MQTT_SENDSTRING]           = makeCommandData(MQTT, {"esp32_keyboard_firetv/cmnd/SENDSTRING"                  }); // payload must be set when calling commandHandler
  // commands[KEYBOARD_MQTT_BACK]                 = makeCommandData(MQTT, {"esp32_keyboard_firetv/cmnd/BACK",                "PRESS"});
  // commands[KEYBOARD_MQTT_HOME]                 = makeCommandData(MQTT, {"esp32_keyboard_firetv/cmnd/HOME",                "PRESS"});
  // commands[KEYBOARD_MQTT_MENU]                 = makeCommandData(MQTT, {"esp32_keyboard_firetv/cmnd/MENU",                "PRESS"});
  // commands[KEYBOARD_MQTT_SCAN_PREVIOUS_TRACK]  = makeCommandData(MQTT, {"esp32_keyboard_firetv/cmnd/SCAN_PREVIOUS_TRACK", "PRESS"});
  // commands[KEYBOARD_MQTT_REWIND_LONG]          = makeCommandData(MQTT, {"esp32_keyboard_firetv/cmnd/REWIND_LONG",         "PRESS"});
  // commands[KEYBOARD_MQTT_REWIND]               = makeCommandData(MQTT, {"esp32_keyboard_firetv/cmnd/REWIND",              "PRESS"});
  // commands[KEYBOARD_MQTT_PLAYPAUSE]            = makeCommandData(MQTT, {"esp32_keyboard_firetv/cmnd/PLAYPAUSE",           "PRESS"});
  // commands[KEYBOARD_MQTT_FASTFORWARD]          = makeCommandData(MQTT, {"esp32_keyboard_firetv/cmnd/FASTFORWARD",         "PRESS"});
  // commands[KEYBOARD_MQTT_FASTFORWARD_LONG]     = makeCommandData(MQTT, {"esp32_keyboard_firetv/cmnd/FASTFORWARD_LONG",    "PRESS"});
  // commands[KEYBOARD_MQTT_SCAN_NEXT_TRACK]      = makeCommandData(MQTT, {"esp32_keyboard_firetv/cmnd/SCAN_NEXT_TRACK",     "PRESS"});
  // commands[KEYBOARD_MQTT_MUTE]                 = makeCommandData(MQTT, {"esp32_keyboard_firetv/cmnd/MUTE",                "PRESS"});
  // commands[KEYBOARD_MQTT_VOLUME_INCREMENT]     = makeCommandData(MQTT, {"esp32_keyboard_firetv/cmnd/VOLUME_INCREMENT",    "PRESS"});
  // commands[KEYBOARD_MQTT_VOLUME_DECREMENT]     = makeCommandData(MQTT, {"esp32_keyboard_firetv/cmnd/VOLUME_DECREMENT",    "PRESS"});
}
```
I also made f few changes to hardware/mqtt.cpp
From:
```
PubSubClient mqttClient(espClient);
```
To:
```
PubSubClient mqttClient(MQTT_SERVER, MQTT_SERVER_PORT, espClient);

```
I also added     mqttClient.setKeepAlive(300); to WiFiEvent
This maybe specific to my MQTT server
```
// WiFi status event
void WiFiEvent(WiFiEvent_t event){
  //Serial.printf("[WiFi-event] event: %d\r\n", event);
  if(event == ARDUINO_EVENT_WIFI_STA_GOT_IP){
    // connection to MQTT server will be done in checkMQTTconnection()
    // mqttClient.setServer(MQTT_SERVER, 1883); // MQTT initialization
    // Set the MQTT keepalive to 300 seconds
    mqttClient.setKeepAlive(300);
    mqttClient.connect("OMOTE"); // Connect using a client id

  }
```

KlausMu, 2024-03-04:
Hi @baerrs this is the wrong issue to discuss it. This issue is about the abstraction branch, which is a [complete different software](https://github.com/CoretechR/OMOTE/tree/abstraction)

It's interesting that with these changes it works for you. I would like to track it down to the real reason.
My first guess is still lack of memory. Did you try the latest version of my software, having a big improvement in memory usage? https://github.com/CoretechR/OMOTE/discussions/58 See latest post at bottom.

1. The comments on `commands[KEYBOARD_MQTT_UP]` are not necessary, you can revert them. These are only commands that get registered. As long as you don't use them in code, the MQTT messages will not be sent
2. with your change in the code, the connection `mqttClient.connect()` is now done at two places in the code. Without having a closer look, I think it is not really bad, but on the other hand no really necessary. Also setting the mqtt server and port like you did is not necessary, since this is already done at a different place.
3. The only substantial change seems to be the `mqttClient.setKeepAlive(300)`

What you could do is:
- try the latest version which is linked above and see if wifi issues are gone
- or, if you understand the memory issue, stay in the current version, reduce lvgl static heap to 32k, use as less guis as possible and see if wifi problems are gone
- revert all your changes, keep only `setKeepAlive`, and retry-

baerrs, 2024-03-04:
@KlausMu  Thank you.
I switched to your forked abstract code.  It works without changing anything.

KlausMu, 2024-03-04:
Ah, that's good to hear. It was always my guess that all WiFi problems are only related to memory.
And to be precise, because my code is not a fork of the "abstract branch"

main branch
https://github.com/CoretechR/OMOTE/tree/main
latest stable version of my software
not abstract, not using c++ classes, and not being object oriented

latest test version
https://github.com/KlausMu/OMOTE/tree/modular-approach
currently including memory optimizations, which is not yet in the main branch

abstract version
https://github.com/CoretechR/OMOTE/tree/abstraction
a completely different software from @MatthewColvin , including classes and object oriented code for hardware abstraction
currently not being further developed

KlausMu, 2024-03-19:
I think we can close this issue, since MQTT Support is now available in the new simulator.
@MatthewColvin do you agree?

MatthewColvin, 2024-05-16:
Yeah makes sense to me :)

Closed 2024-05-16.

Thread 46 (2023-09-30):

> So my PCB came without screen and battery. Anyone can suggest any nice screens from AliExpress that will suit the housing. Battery as well?

gacekk, 2023-09-30:
> So my PCB came without screen and battery. Anyone can suggest any nice screens from AliExpress that will suit the housing. Battery as well?

I'm not sure where you're located but for reference I bought these from Little Bird Electronics and they fit perfectly.
1 Lithium Ion Battery - 3.7v 2000mAh . Partno:  AF-2011
1 2.8" TFT Display - 240x320 with Capacitive Touchscreen. Partno: AF-2770

_Originally posted by @tnph in https://github.com/CoretechR/OMOTE/issues/3#issuecomment-1741681138_

For all interested the display appears to be Adafruit 1774

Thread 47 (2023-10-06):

Bluetooth Keyboard and mouse mode

MatthewColvin, 2023-10-06:
Make the remote able to advertise and connect to HID hosts to allow keyboard and mouse control of devices like android tv.

Wildpig954, 2023-10-06:
This function would be great. My Harmony hub has keyboard and when I change between TV, windows and nvidia shield the keyboard switches too. This would be a great option to have.

phant0mias, 2023-10-06:
Hi,
that is not difficult. I already tried it.

you can use:
https://github.com/T-vK/ESP32-BLE-Keyboard
or
https://github.com/lemmingDev/ESP32-BLE-Gamepad

With the gamepad library I managed to use the remote control with the Amazon Fire Stick. I can write this weekend what commands from the gamepad are used to control the fire stick.

When you add these libraries you should use the newest platformio.ini file to get more flash memory (https://github.com/CoretechR/OMOTE/pull/43)

A problem is that the boot time is getting higher

phant0mias, 2023-10-08:
For controlling a amazon fire stick I use the bleGamepad class. After connecting the device in the fire stick settings as gamecontroller you can send the remote commands.
Automatic reconnect after power down the TV and remote is working too.

You have to experiment with it and check the examples of this class.

If somebody found some additional information like how to change the channel and volume with bluetooth it would be great.

I had an effort with the followings commands:

#include <BleGamepad.h>

BleGamepad m_bleGamepad

void setup()
{
.....
    BleGamepadConfiguration bleGamepadConfig;
    bleGamepadConfig.setAutoReport(true);
    bleGamepadConfig.setControllerType(CONTROLLER_TYPE_GAMEPAD);
    bleGamepadConfig.setIncludeStart(true);
    bleGamepadConfig.setIncludeSelect(true);
    bleGamepadConfig.setIncludeMenu(true);
    bleGamepadConfig.setIncludeHome(true);
    bleGamepadConfig.setIncludeBack(true);

    bleGamepad.begin(&bleGamepadConfig);
....
}

as commands you can send:

// Back
bleGamepad.pressBack();
delay( 5 );
bleGamepad.releaseBack();

// Down
bleGamepad.setHat1(HAT_DOWN);
delay( 5 );
bleGamepad.setHat1(HAT_CENTERED);

// Home
bleGamepad.press(BUTTON_12);
delay( 5 );
bleGamepad.release(BUTTON_12);

// Left
bleGamepad.setHat1(HAT_LEFT);
delay( 5 );
bleGamepad.setHat1(HAT_CENTERED);

// Menu
bleGamepad.press(BUTTON_11);
delay( 5 );
bleGamepad.release(BUTTON_11);

// OK
bleGamepad.press(BUTTON_1);
delay( 5 );
bleGamepad.release(BUTTON_1);

// Right
bleGamepad.setHat1(HAT_RIGHT);
delay( 5 );
m_bleGamepad.setHat1(HAT_CENTERED);

// Up
m_bleGamepad.setHat1(HAT_UP);
delay( 5 );
m_bleGamepad.setHat1(HAT_CENTERED);

phant0mias, 2023-10-09:
I opened a discussion for this theme

https://github.com/CoretechR/OMOTE/discussions/48

KlausMu, 2024-03-13:
Issue closed, because in main BLE keyboard support is available. FireTV can be controller, others as well.

Closed 2024-03-13.

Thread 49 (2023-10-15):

Case manufacturing like https://www.wiphone.io/

devenator, 2023-10-15:
Is a Case manufacturing like https://www.wiphone.io (basically an aluminum profile with two plates, eighter also aluminum or plexiglass) feasible? Does anyone know a company that does somethin kline that...?

devenator, 2023-10-15:
Is a Case manufacturing like https://www.wiphone.io (basically an aluminum profile with two plates, eighter also aluminum or plexiglass) feasible? Does anyone know a company that does somethin kline that...?

GordonZed, 2024-04-22:
The wiphone case doesn't look to me (at least from the hero image on the homepage) like just two aluminum plates; it looks like aluminum that's been stamped (die cut *and* bent/folded), so while anything is feasible if you're willing to pay for it, it's far more feasible if you design something that requires only cutting, because any service that provides CNC milling or laser cutting services will be able to do that for far less expense.

I would look at something like [ponoko.com](https://ponoko.com), although I haven't looked into them in quite a while and they seem to have gone from a simple laser cutting service for hobbyists to targeting small tech startups, but regardless, a quote is free, so the worst that can happen is the quote is more than you want to spend, and you either keep looking, or consider cheaper materials. I'd also look at [Shapeways](https://www.shapeways.com), who are known for 3D printing, but they provide a wide range of manufacturing and prototyping services, and again, a quote is free, and every quote that hurts is an educational experience.

What I would do is check local marketplaces (Craigslist, Kijiji [this might be Canada only], FB Mktplce, etc.) and see if you can find someone with a hobby shop who provides custom laser-cutting/CNC milling as a side hustle.

In the end, all of this is available, but depending on the desired materials/processes, can be prohibitively expensive. Your best bet would be laser cut acrylic, and maybe a thin veneer of brushed aluminum on the exterior faces for the final look. It's very cheap to get CNC cut acrylic parts, but aluminum beyond, say a sixteenth or two is probably going to increase in price rapidly as the material thickness goes up.

Closed 2025-04-06.

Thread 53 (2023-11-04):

Battery discharge protection

olup, 2023-11-04:
Looking at the schematics - could you explain what prevents the battery to drop below safe voltage ?

CoretechR, 2023-11-10:
Usually pouch style lipo cells have an integrated protection circuit for undervoltage. For a commercial product, it would make sense to put this protection on the board in form of some IC.

Closed 2024-06-17.

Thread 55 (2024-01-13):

Battery charge status not reliable

KlausMu, 2024-01-13:
Hi Maximilian,

Great project, thanks a lot for it!

On my board (created with your PCB files), "battery_ischarging = !digitalRead(CRG_STAT);" does not deliver reliable results.
Sometimes result is correct, sometimes not. Wrong detection happens both when battery is empty or when it is full.
Seems to be a little bit random.

Could it be that you cannot both connect a LED to STAT and at the same time digitally read the state of STAT?
The MCP73831 datasheet states:
`STAT is an output for connection to an LED for charge status indication. **Alternatively**, a pull-up resistor can be
applied for interfacing to a host microcontroller.`
So maybe the digital read of STAT is not longer reliable if a LED is connected.
Unfortunately STAT is connected to GPIO21, which cannot read analog values.

What do you think?

CoretechR, 2024-01-13:
Hi Klaus, I have not heard about this problem before. The charging indication always seemed reliable enough to me. Do you have a multimeter to measure the voltage on the charging status pin?

KlausMu, 2024-01-14:
Ok. Battery is almost full, 4.1 V.

1. Charger connected:
LED on, Voltage on STAT is 0.11 V, !digitalRead(CRG_STAT) == true

2. Charger not connected:
LED off, Voltage on STAT is 1.12 V, !digitalRead(CRG_STAT) == true

CoretechR, 2024-01-14:
Thanks for checking this! Unfortunately I just found a problem with my circuit:
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
The charger is supplied by VBUS and I connected the status output directly to the ESP32.
That's bad in two ways:
1. It's a push-pull output so when charging is complete, the charger sets the status pin to 5V. The clamping diodes in the ESP32 will protect the controller to some degree, but that's not something to rely on.
2. When USB is disconnected, there is no pull-up voltage to set the status to a defined level, which might explain your issue.

I'm really sorry that I overlooked this. I even used a similar circuit in prior projects, somehow without any problems.

As for the ESP32 getting damaged, I think we should be OK given the number of working boards in circulation. To fix your unreliable status indicator, the LED could be disconnected from VBUS and wired to +3.3V. In any case I will create a REV3 to fix this and other minor issues.

KlausMu, 2024-01-14:
Ok, great, that you found this issue. I also think 5V on the ESP32 input shouldn't be a real problem, I also had this before in other projects.

If you want to, you could think about a circuit which recognizes all three states. Currently HIGH-Z cannot be recognized. But it is only nice to have ... https://electrical.codidact.com/posts/286209

CoretechR, 2024-01-14:
Thank you for pointing me to this problem in the first place! And sure, if I do a new PCB revision, I will also look into a proper detection circuit.

Closed 2024-06-17.

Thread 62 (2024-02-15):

C15 too small for reliable uploads with Windows 11

KlausMu, 2024-02-15:
Hi Max,

I always had the issue that it was not possible for me to do the firmware upload with PlatformIO on Windows.
On the same computer, same USB port, same hardware, the upload was possible from WSL2.
Obviously the drivers on Windows and Ubuntu handle EN and GPIO0 slightly differently.
It was always a pain for me to switch between Windows for compiling and WSL2 for uploading.

On Windows this is a [widely known problem.](https://github.com/espressif/esptool/issues/706)
Sometimes older driver versions help, but not in my case. I tried a lot of different driver versions and driver settings.

I have only basic knowledge about wiring, PCBs and so on, but I found this:
https://docs.espressif.com/projects/esptool/en/latest/esp32/advanced-topics/boot-mode-selection.html#boot-mode
_If this circuitry is implemented (all Espressif boards have it), adding a capacitor between the EN pin and GND **(in the 1uF-10uF range)** is necessary for the reset circuitry to work reliably. This is shown in the ESP32 Module section of the schematic._

As far as I understand, the OMOTE has 100 nF as capacitor (C15) between EN and GND. Espressif recommends 1uF-10uF. So I added 10uF in parallel.

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

This did the trick. No more switching between Windows and WSL2.

As you are currently working on a new version of the PCB, maybe you want to think about increasing C15.

CoretechR, 2024-02-15:
Hi Klaus, that is a good point. I never had a problem with the automatic reset on my own boards with 100nF but Espressif does indeed recommend a higher capacitance. They somehow do not follow their own recommendation and only put 100nF on all their evaluation boards, but that might explain why the reset never works on those. Maybe they wanted to save 1 cent on their boards.
I will definitely put that on my list for the new revision, thank you!

Closed 2024-06-17.

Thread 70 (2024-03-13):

Intermittent LCD initialization failure

JustMe-NL, 2024-03-13:
When the rev.3 hardware is run from battery the remote sometimes (probably) does not initialize the LCD correctly. The result is that the backlight is lit but the screen is blank. The user-led pulses its heartbeat and the buttons do work correctly. Usually I can let the remote rest until the screen shuts off and the ESP32 goes to sleep. After that usually the screen functions normal again.

Does anybody else experience this phenomenon and what could be the resolution? Change the start delay, add some capacitors or something else?

The LCD is an Adafruit original and run at the default 40MHz.

KlausMu, 2024-03-13:
Yes, about every 50th or 100th restart I have the same.
I already had a discussion with @CoretechR about it.

If it happens more often to you, you could try to play around with this code in main branch
https://github.com/CoretechR/OMOTE/blob/ee68361273f4d0262138b418d8d783899c708520/Platformio/src/hardware/tft.cpp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

or this code in lvgl_simulator feature branch
https://github.com/CoretechR/OMOTE/blob/51a6c7306c4c27dcf86ad88e97a793eef4b950d0/Platformio/hardware/ESP32/tft_hal_esp32.cpp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

In hardware rev 1 the code was necessary to prevent the ESP32 from brownout when powering the TFT chip.

Now, the problem is not the ESP32 brownout anymore, but it seems that the TFT chip sometimes does not boot correctly. You could

- remove the code completely
- play around with loop counter (more or less loop passes)
- set more or other delays in between

**The last statement always has to be `digitalWrite(LCD_EN_GPIO, LOW);`, which powers the TFT chip.**

@CoretechR any other ideas on how it could be solved in software?

CoretechR, 2024-03-13:
@JustMe-NL Can you say how often this roughly happens? Does it only happen when the device is battery powered? Intermittent problems like this are always tricky to debug.
It would definitely be interesting to see if the software workaround for Rev 1 has any effect on this.
(The code changes how quickly the supply voltage for the display rises)

At the moment I am unable to reproduce this issue with my remote by just waking it up from standby. I have to manually toggle the reset pin of the display to get a static white image.

KlausMu, 2024-03-13:
To me it also happens when it is USB powered, without battery.
I don't know if removing the loop code for rev2 and rev3 helped. The code is in there only for some days. I didn't had this effect since then, but time is to short to say if it solved the issue.

JustMe-NL, 2024-03-13:
As far as I can recall I have only seen this when on battery. At first I thought I had some sort of bad battery with not enough capacity or a large internal resistance to provide the needed current. But I saw the behavior on two different batteries.

Resetting only the ESP32 does not resolve this by the way, both devices need to reset to resolve the issue which thankfully always happens after a couple of seconds of sleep.

If I have some time I'll add some wires and check the voltagecurves on the scope.

CoretechR, 2024-03-13:
OK, if you could check 3.3V and VSW voltages with a scope, that would be interesting.

CoretechR, 2024-03-14:
Thank you very much for your findings, @JustMe-NL!
I don't remember seeing this behavior before. The ESP32 needed a lot of convincing to keep the LCD_EN and LCD_BL pins in a high state during sleep and to correctly handle the wakeup. But I always thought it would start cleanly like in you second screenshot.
This can definitely have an effect on display not initializing correctly.

KlausMu, 2024-03-14:
Maybe it is worth checking that everything is still in correct order with the new modulare approach.
When everything was in one single file `main.cpp`, things from sleep and tft were intertwingled a lot. I broke them up in separate modules.
Now we have init_tft()  and init_sleep() at setup-time.
And enterSleep() when going to sleep at runtime.

In the first version of main.cpp, code fom init_tft() and init_sleep() was mixed.
```
  --> this is now in init_tft()
  pinMode(LCD_EN, OUTPUT);
  digitalWrite(LCD_EN, HIGH);

  --> this is now in init_sleep()
  gpio_hold_dis((gpio_num_t)LCD_EN);

  --> this is now in init_tft()
  ledc_channel_config_t ledc_channel_left;
```
Now, first init_sleep() is called, afterwards init_tft()

JustMe-NL, 2024-03-14:
I saw the backlight flash as well today. Maybe it has something to do with the setup. Q4 has a gate threshold voltage of -0.4 to -1.2. But the ESP32 can have a Vout high as low as 0.8 x Vdd which is Vdd - 0,66 @ 3V3. Enough to maybe partially conduct Q4, this could explain the weird curve: in the HIGH state, Q4 partially conducts (I did not measure Vgs though).

A solution could then be to keep the outputs as input (high-z) until we are ready to use them, you can set the outputlevel before the GPIO is defined as output (quoting https://www.esp32.com/viewtopic.php?t=28677).

CoretechR, 2024-03-15:
I soldered wires to 3.3V, VSW, LCD_EN and LCD_BL and recorded the startup.
This is what it looks like with the old (single main file) code:
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

And this is with the new modular code:
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

Something does not seem quite right with the initialization. And this would at least explain the short backlight flickering.

KlausMu, 2024-03-15:
Ok, I think I understand what is going on. I wanted the IMU to be initialized before TFT. Both are using I2C.
To init IMU, the TFT needs to be powered, because otherwise the I2C bus is disturbed by the non powered tft.
So I added
```
void init_hardware_general_HAL(void) {
  // For I2C to work correctly, the tft has to be powered.
  // Otherwise the IMU cannot be initialized.
  // The tft touch controller, being on the same I2C bus, seems to disturb if not powered.
  pinMode(LCD_EN, OUTPUT);
  digitalWrite(LCD_EN, LOW);                         <-- this is different

  // SDA and SCL need to be set explicitly, because for IMU you cannot set it explicitly in the constructor.
  // Configure i2c pins and set frequency to 400kHz
  Wire.begin(SDA_GPIO, SCL_GPIO, 400000);
```
at the very beginning of setup

As a test, could you please

1. in main.cpp, deactivate "init_hardware_general();"

2. in "hardware/ESP32/tft_hal_esp32.cpp", put
add
```
  Wire.begin(19, 22, 400000);
```
before
```
  touch.begin(128); // Initialize touchscreen and set sensitivity threshold
```
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
KlausMu, 2024-03-24:
I think the fps reported by lvgl is the result of different things. SPI frequency is only one part. CPU load and how long it takes to calculate the next frame is most likely another player.

And LVGL uses a fixed limit of
```
/*Default display refresh period. LVG will redraw changed areas with this period time*/
#define LV_DISP_DEF_REFR_PERIOD 30      /*[ms]*/
```
24 MHz: I definitely can see a jerky animation, and touch doesn't behave very well
32 MHz: much better
40 MHz: a little better, recognizable, but not that much of a big improvement

So from what I can recognize, there is a big improvement from 24 to 32, and a smaller improvement from 32 to 40.

@CoretechR I committed 5 ms

JustMe-NL, 2024-03-27:
Ok, at 40 MHz I got white screen problems but after some carefull testing I can safely say that it works reliable at 38MHz on my screen & hardware. I have not figured out yet if we could change something in the hardware to obtain those desired higher speeds (some extra caps maybe?). Projects that boast about higher speeds usually do not post their schematic or hardware layout.

My added APX803S could be unnecessary but maybe consider adding it as an fail-safe option to hardware rev 4, just add the footprint and do not populate it unless you have starting issues with the screen.

CoretechR, 2024-03-27:
Interesting, that there is such a big difference with different SPI speeds.
I will definitely add an optional reset generator to the next revision. Thank you for the suggestion!

JustMe-NL, 2024-04-05:
The saga continues when you follow the white screen into the rabbit hole, or something like that.

So my Omote SPI runs at 78MHz with an apx803 and TFT_RST set to GPIO0. This means the library does not issue a soft reset. And I have not seen a white screen since until I had to check my USB port (because a macOS update probably screwed with the ch3040 driver). That is great news! After opening the case and resoldering the USB, I had some issues but they disappeared after I reseated the LCD cable (and the SPI speed had no influence whatsoever).

And now for the fun part: I made a second Omote without any hardware alterations and loaded the exact same code and it too has zero issues, running at 78MHz but without the apx803 and without the soft reset because the TFT_RST is still configured to GPIO0.

Hindsight is always 20/20 right? Looking back I think all problems disappeared after I restarted my customizations from scratch with the scene_selection (love it by the way!) repo. Somewhere I previously must have overlooked something in the startup sequence somewhere in the code.

For those folks who have read until here and are having the same problems, check these things first:

- Make sure you run the latest code with all the hardware timing fixes.
- Make sure your LCD is firmly seated in the socket.
- If all else fails, try lowering the SPI frequency in platformio.ini.

KlausMu, 2024-04-05:
Oh, that's good to hear, thank you for the update.
Since the branch "scene-selection" seems to be good, I brought it back to main.

KlausMu, 2024-04-05:
One more thing I found out about SPI. There exists the so called [GPIO Matrix and IO_MUX](https://docs.espressif.com/projects/esp-idf/en/v3.1.6/api-reference/peripherals/spi_master.html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)

IO_MUX means, you are using the SPI pins that are intended for that use. In that case you can use up to 80 MHz.
GPIO Matrix means, you are using different GPIO pins for SPI. In that case you can use only up to 40 MHz.

OMOTE is using IO_MUX (SPI 3 or VSPI). OMOTE is not using MISO (GPIO 19) for SPI. But GPIO 19 is used for SDA (I2C).

Don't know if this different use of GPIO19 is of any relevance or if it could disturb or limit SPI.

CoretechR, 2024-04-05:
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

Yes, with the way the display is connected we can make use of the IO_MUX and drive the display at 80MHz. But I never heard of unused pins causing problems, especially at below 40MHz. Technically, chip select, QUADWP and QUADHD are also part of the SPI IO_MUX. But who knows, the ESP32 works in weird ways sometimes.

JustMe-NL, 2024-04-06:
> Thank you for the interesting update, @JustMe-NL! You mean 38 MHz, right? Glad to hear that your remote is running without issues now. I included a spot for the APX803S in PCB revision 4 anyway.

Nope, 78MHz as in "-D SPI_FREQUENCY=78000000". But to be frank, I did not check this with spi_device_get_actual_freq.

JustMe-NL, 2024-04-13:
After adding
`
Serial.printf("SPI clock set to: %d\r\n", spi_get_actual_clock(APB_CLK_FREQ, SPI_FREQUENCY, 128));
`
the serial console informs me the frequency is set to 80MHz, and working fine on multiple LCD screens.

Closed 2024-04-13.

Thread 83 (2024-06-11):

PCB Revision 4

osmanates, 2024-06-11:
Hi,

I saw in the schematic some components like C27, U10 is marked with X. Are these not supported to be in the pcb? BOM.csv file seems to not have these but Kicad schematic and pcb files seems to have these components. I plan to get PCBA service from JLCPCB so İ will need to upload the gerber files, bom and cpl. Not sure what files to use since those have these components Any help here is appreciated.

KlausMu, 2024-06-13:
@CoretechR can you help?

CoretechR, 2024-06-13:
U10 is an optional reset generator for the display controller (see #70). U10 and C27 are marked as unpopulated in the schematic.
If somehow these two components ended up in your PCBA order, you can remove them from the BOM. Or you can leave the in. Functionally it should not make a difference.

osmanates, 2024-06-13:
Thanks. There are also C18, C19 and J4. Same applies for them as well?

CoretechR, 2024-06-14:
Yes, those should not be soldered to the PCB by default.

Closed 2024-06-17.

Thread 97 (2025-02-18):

Compiling for windows_64bit environment to use Simulator

win001, 2025-02-18:
PS D:\work\kiot_kiox\OMOTE\Platformio> pio run -e windows_64bit
Processing windows_64bit (platform: native@^1.2.1)
------------------------------------------------------------------------------------------------------------------------------------------------
Verbose mode can be enabled via `-v, --verbose` option
LDF: Library Dependency Finder -> https://bit.ly/configure-pio-ldf
LDF Modes: Finder ~ chain, Compatibility ~ soft
Found 2 compatible libraries
Scanning dependencies...
Dependency Graph
|-- lvgl @ 8.4.0
|-- lv_drivers @ 9.0.0-dev+sha.7482c7c
Building in release mode
Compiling .pio\build\windows_64bit\hardware\windows_linux\battery_hal_windows_linux.o
Compiling .pio\build\windows_64bit\hardware\windows_linux\hardware_general_hal_windows_linux.o
Compiling .pio\build\windows_64bit\hardware\windows_linux\heapUsage_hal_windows_linux.o
Compiling .pio\build\windows_64bit\hardware\windows_linux\infrared_receiver_hal_windows_linux.o
Compiling .pio\build\windows_64bit\hardware\windows_linux\infrared_sender_hal_windows_linux.o
Compiling .pio\build\windows_64bit\hardware\windows_linux\keyboard_ble_hal_windows_linux.o
g++: fatal error: no input files
compilation terminated.
g++: fatal error: no input files
compilation terminated.
Compiling .pio\build\windows_64bit\hardware\windows_linux\keypad_gui\key_map.o
g++: fatal error: no input files
compilation terminated.
Compiling .pio\build\windows_64bit\hardware\windows_linux\keypad_gui\keypad_gui.o
Compiling .pio\build\windows_64bit\hardware\windows_linux\keypad_keys_hal_windows_linux.o
Compiling .pio\build\windows_64bit\hardware\windows_linux\lib\MQTT-C\src\mqtt.o
Compiling .pio\build\windows_64bit\hardware\windows_linux\lib\MQTT-C\src\mqtt_pal.o
*** [.pio\build\windows_64bit\hardware\windows_linux\battery_hal_windows_linux.o] Error 1
*** [.pio\build\windows_64bit\hardware\windows_linux\hardware_general_hal_windows_linux.o] Error 1
*** [.pio\build\windows_64bit\hardware\windows_linux\heapUsage_hal_windows_linux.o] Error 1
g++: fatal error: no input files
compilation terminated.
g++: fatal error: no input files
compilation terminated.
g++: fatal error: no input files
compilation terminated.
*** [.pio\build\windows_64bit\hardware\windows_linux\keyboard_ble_hal_windows_linux.o] Error 1
g++: fatal error: no input files
compilation terminated.
*** [.pio\build\windows_64bit\hardware\windows_linux\keypad_gui\key_map.o] Error 1
*** [.pio\build\windows_64bit\hardware\windows_linux\infrared_sender_hal_windows_linux.o] Error 1
*** [.pio\build\windows_64bit\hardware\windows_linux\infrared_receiver_hal_windows_linux.o] Error 1
g++: fatal error: no input files
compilation terminated.
g++: fatal error: no input files
compilation terminated.
gcc: fatal error: no input files
compilation terminated.
gcc: fatal error: no input files
compilation terminated.
*** [.pio\build\windows_64bit\hardware\windows_linux\keypad_keys_hal_windows_linux.o] Error 1
*** [.pio\build\windows_64bit\hardware\windows_linux\lib\MQTT-C\src\mqtt_pal.o] Error 1
*** [.pio\build\windows_64bit\hardware\windows_linux\keypad_gui\keypad_gui.o] Error 1
*** [.pio\build\windows_64bit\hardware\windows_linux\lib\MQTT-C\src\mqtt.o] Error 1
========================================================== [FAILED] Took 1.79 seconds ==========================================================

Environment    Status    Duration
-------------  --------  ------------
windows_64bit  FAILED    00:00:01.794
==================================================== 1 failed, 0 succeeded in 00:00:01.794 ====================================================

KlausMu, 2025-03-31:
closed because of no further action

Closed 2025-03-31.

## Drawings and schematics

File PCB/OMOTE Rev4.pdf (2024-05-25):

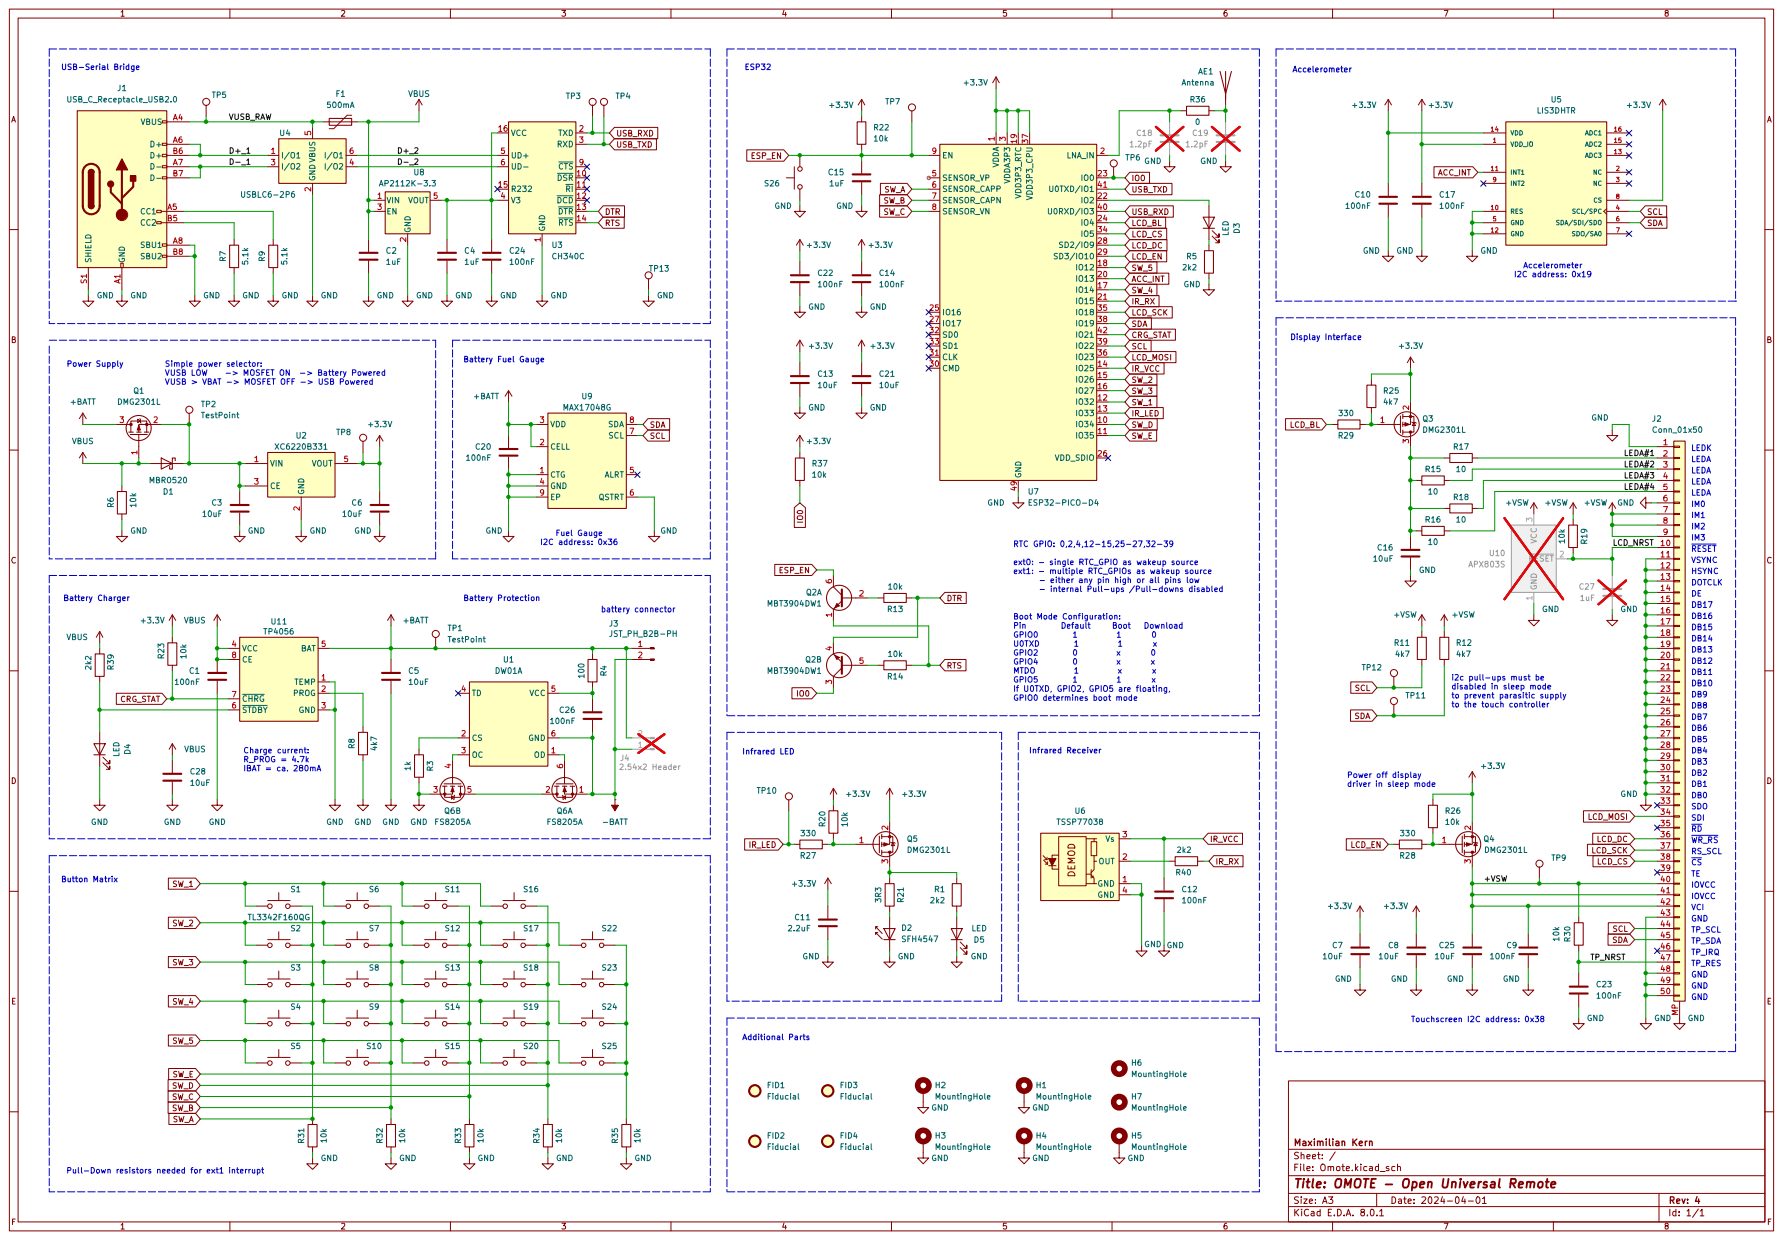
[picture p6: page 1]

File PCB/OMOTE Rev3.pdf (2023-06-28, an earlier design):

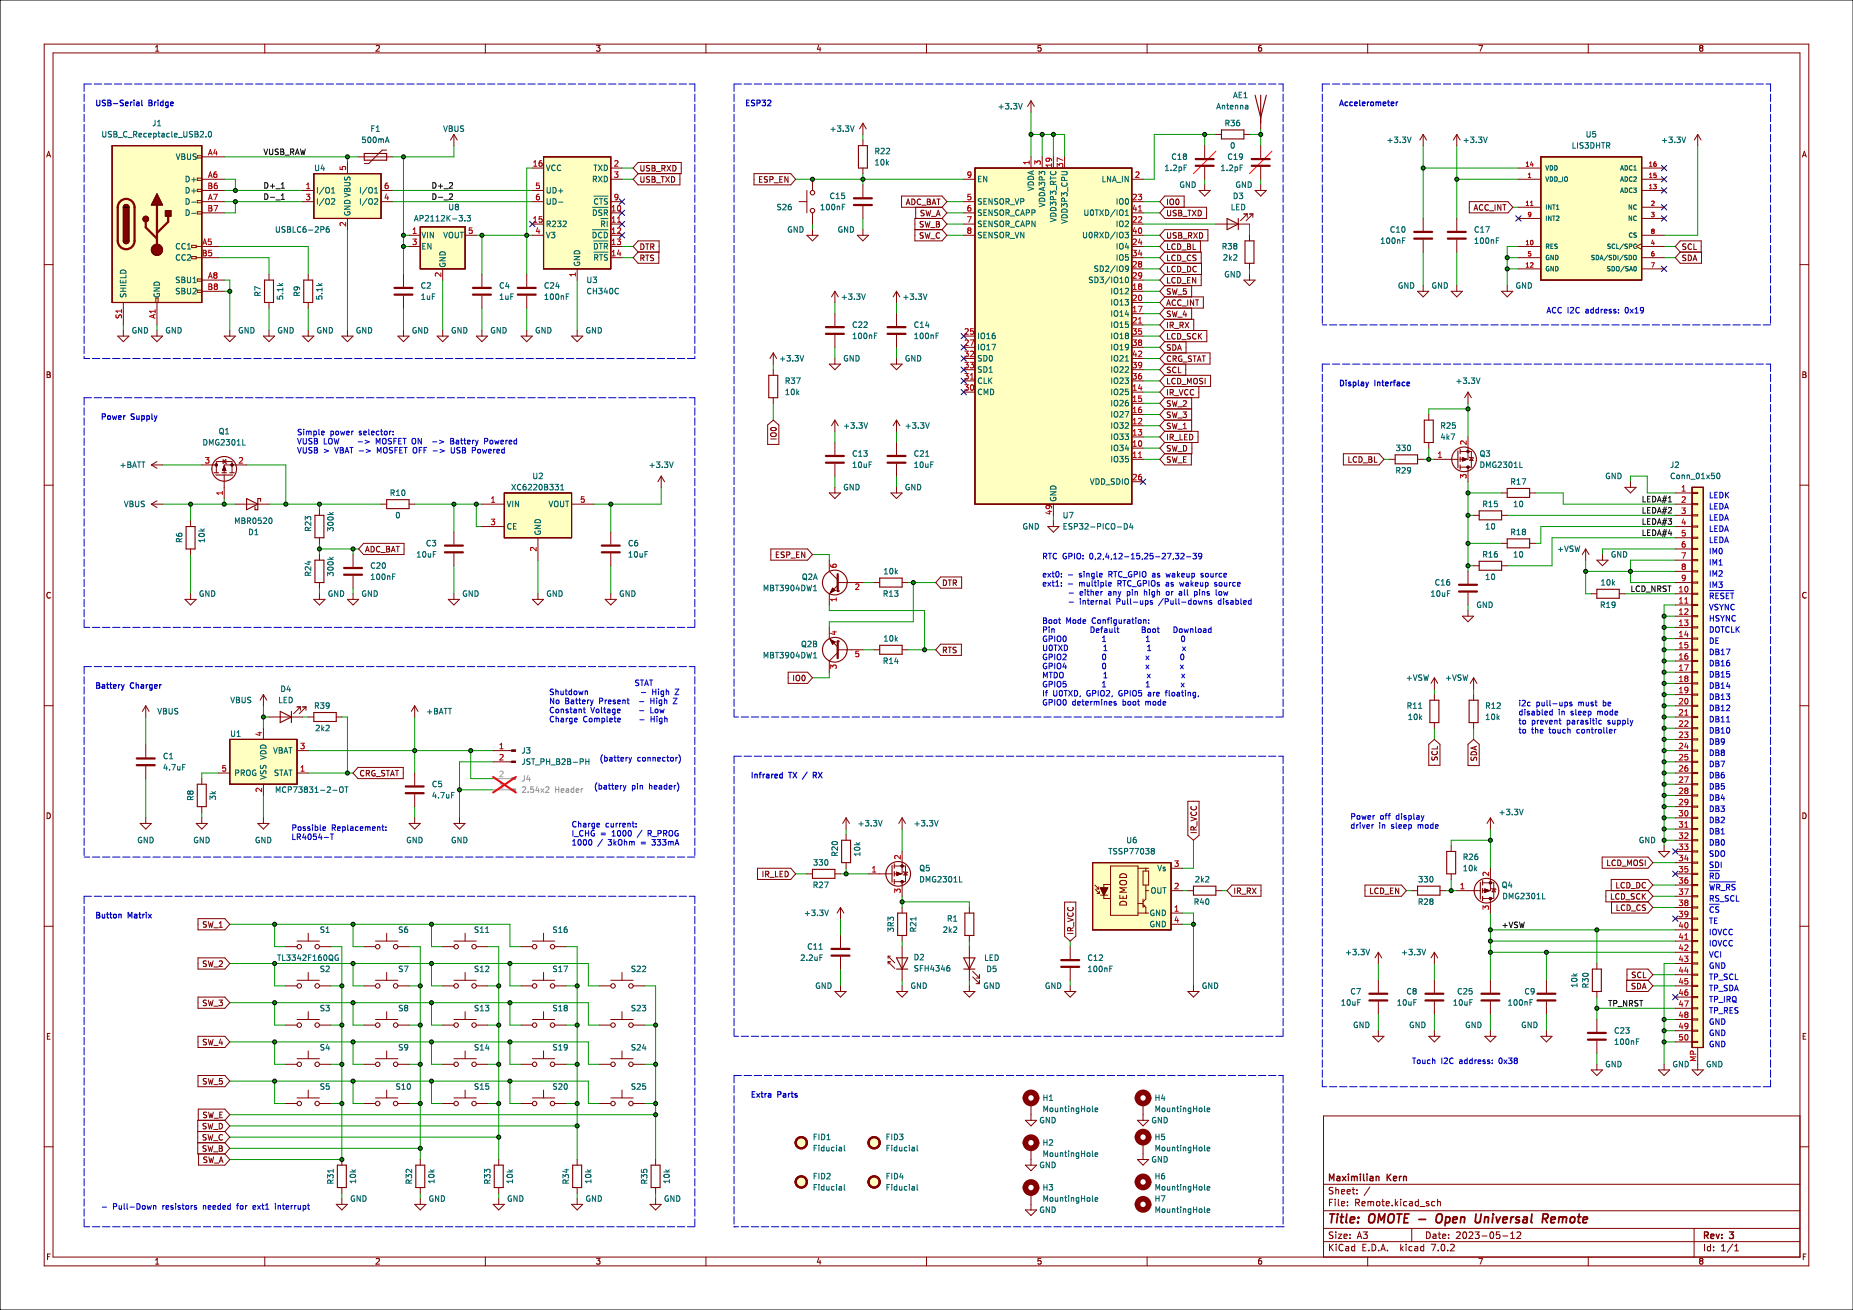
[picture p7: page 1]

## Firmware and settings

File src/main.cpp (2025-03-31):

// OMOTE firmware for ESP32
// 2023-2025 Maximilian Kern, Klaus Musch

#include "applicationInternal/omote_log.h"
// init hardware and hardware loop
#include "applicationInternal/hardware/hardwarePresenter.h"
// register devices and their commands
//   special
#include "devices/misc/device_specialCommands.h"
#include "applicationInternal/commandHandler.h"
//   keyboards
#if (ENABLE_KEYBOARD_MQTT == 1)
#include "devices/keyboard/device_keyboard_mqtt/device_keyboard_mqtt.h"
#endif // ENABLE_KEYBOARD_MQTT
#if (ENABLE_KEYBOARD_BLE == 1)
#include "devices/keyboard/device_keyboard_ble/device_keyboard_ble.h"
#endif // ENABLE_KEYBOARD_BLE
//   TV
#include "devices/TV/device_samsungTV/device_samsungTV.h"
//#include "devices/TV/device_lgTV/device_lgTV.h"
//   AV receiver
#include "devices/AVreceiver/device_yamahaAmp/device_yamahaAmp.h"
//#include "devices/AVreceiver/device_denonAvr/device_denonAvr.h"
//#include "devices/AVreceiver/device_lgsoundbar/device_lgsoundbar.h"
//   media player
#include "devices/mediaPlayer/device_appleTV/device_appleTV.h"
//#include "devices/mediaPlayer/device_lgbluray/device_lgbluray.h"
//#include "devices/mediaPlayer/device_samsungbluray/device_samsungbluray.h"
//#include "devices/mediaPlayer/device_shield/device_shield.h"
//   misc
#include "devices/misc/device_smarthome/device_smarthome.h"
//#include "devices/misc/device_airconditioner/device_airconditioner.h"
// register gui and keys
#include "applicationInternal/gui/guiBase.h"
#include "applicationInternal/gui/guiRegistry.h"
#include "guis/gui_sceneSelection.h"
#include "guis/gui_irReceiver.h"
#include "guis/gui_settings.h"
#include "guis/gui_numpad.h"
#include "guis/gui_BLEpairing.h"
#include "devices/AVreceiver/device_yamahaAmp/gui_yamahaAmp.h"
#include "devices/mediaPlayer/device_appleTV/gui_appleTV.h"
#include "devices/misc/device_smarthome/gui_smarthome.h"
//#include "devices/misc/device_airconditioner/gui_airconditioner.h"
#include "applicationInternal/keys.h"
#include "applicationInternal/gui/guiStatusUpdate.h"
// register scenes
#include "scenes/scene__default.h"
#include "scenes/scene_allOff.h"
#include "scenes/scene_TV.h"
#include "scenes/scene_fireTV.h"
#include "scenes/scene_chromecast.h"
#include "scenes/scene_appleTV.h"
#include "applicationInternal/scenes/sceneHandler.h"

#if defined(ARDUINO)
// in case of Arduino we have a setup() and a loop()
void setup() {

#elif defined(WIN32) || defined(__linux__) || defined(__APPLE__)
// in case of Windows/Linux, we have only a main() function, no setup() and loop(), so we have to simulate them
// forward declaration of loop()
void loop(unsigned long *pIMUTaskTimer, unsigned long *pUpdateStatusTimer);
// main function as usual in C
int main(int argc, char *argv[]) {
#endif

  // --- Startup ---
  Serial.begin(115200);
  // do some general hardware setup, like powering the TFT, I2C, ...
  init_hardware_general();
  // get wakeup reason
  init_sleep();
  // Restore settings from internal flash memory
  init_preferences();
  // blinking led
  init_userled();
  // startup SD card
  #if(OMOTE_HARDWARE_REV >= 5)
  // SD card is currently not used, so save some time on startup and don't init the SD card
  // init_SD_card();
  #endif

  // setup IR sender
  init_infraredSender();

  // register commands for the devices
  register_specialCommands();
  //   TV
  register_device_samsungTV();
  //register_device_lgTV();
  //   AV receiver
  register_device_yamahaAmp();
  //register_device_denonAvr();
  //register_device_lgsoundbar();
  //   media player
  register_device_appleTV();
  //register_device_lgbluray();
  //register_device_samsungbluray();
  //register_device_shield();
  //   misc
  register_device_smarthome();
  //register_device_airconditioner();

  #if (ENABLE_KEYBOARD_MQTT == 1)
  register_device_keyboard_mqtt();
  #endif
  #if (ENABLE_KEYBOARD_BLE == 1)
  register_device_keyboard_ble();
  #endif
  register_keyboardCommands();

  // Register the GUIs. They will be displayed in the order they have been registered.
  register_gui_sceneSelection();
  register_gui_irReceiver();
  register_gui_settings();
  register_gui_appleTV();
  register_gui_numpad();
  #if (ENABLE_KEYBOARD_BLE == 1)
  register_gui_blepairing();
  #endif
  register_gui_smarthome();
  //register_gui_airconditioner();
  register_gui_yamahaAmp();
  // Only show these GUIs in the main gui list. If you don't set this explicitely, by default all registered guis are shown.
  #if (USE_SCENE_SPECIFIC_GUI_LIST != 0)
  main_gui_list =
    {tabName_yamahaAmp, tabName_sceneSelection, tabName_smarthome, tabName_settings, tabName_irReceiver
    #if (ENABLE_KEYBOARD_BLE == 1)
    , tabName_blepairing
    #endif
    };
  #endif

  // register the scenes and their key_commands_*
  register_scene_defaultKeys();
  register_scene_TV();
  register_scene_fireTV();
  register_scene_chromecast();
  register_scene_appleTV();
  register_scene_allOff();
  // Only show these scenes on the sceneSelection gui. If you don't set this explicitely, by default all registered scenes are shown.
  set_scenes_on_sceneSelectionGUI({scene_name_TV, scene_name_fireTV, scene_name_chromecast, scene_name_appleTV});

  // init GUI - will initialize tft, touch and lvgl
  init_gui(); // This has to come before any other i2c devices are initialized, otherwise the i2c bus will not be powered
  setLabelActiveScene();
  gui_loop(); // Run the LVGL UI once before the loop takes over
  
  // Power Pin and battery monitor definition
  init_battery();

  // init BLE keyboard. Has to be after init_gui (because of powered I2C) and after init_battery (because of fuel gauge init)
  #if (ENABLE_KEYBOARD_BLE == 1)
  init_keyboardBLE();
  #endif

  // setup keyboard matrix driver
  init_keys();

  // setup the Inertial Measurement Unit (IMU) for motion detection. Has to be after init_gui(), otherwise I2C will not work
  init_IMU();

  // init WiFi - needs to be after init_gui() because WifiLabel must be available
  #if (ENABLE_WIFI_AND_MQTT == 1)
  init_mqtt();
  #endif

  omote_log_i("Setup finished in %lu ms.\r\n", millis());

  #if defined(WIN32) || defined(__linux__) || defined(__APPLE__)
  // In Windows/Linux there is no loop function that is automatically being called. So we have to do this on our own infinitely here in main()
  unsigned long IMUTaskTimer = 0;
  unsigned long updateStatusTimer = 0;
  while (1)
    loop(&IMUTaskTimer, &updateStatusTimer);
  #endif

}

// Loop ------------------------------------------------------------------------------------------------------------------------------------
#if defined(ARDUINO)
unsigned long IMUTaskTimer = 0;
unsigned long updateStatusTimer = 0;
unsigned long *pIMUTaskTimer = &IMUTaskTimer;
unsigned long *pUpdateStatusTimer = &updateStatusTimer;
void loop() {
#elif defined(WIN32) || defined(__linux__) || defined(__APPLE__)
void loop(unsigned long *pIMUTaskTimer, unsigned long *pUpdateStatusTimer) {
#endif

  // --- do as often as possible --------------------------------------------------------
  // update backlight and keyboard brightness. Fade in on startup, dim before going to sleep
  update_backlightBrightness();
  #if(OMOTE_HARDWARE_REV >= 5)
    update_keyboardBrightness();
  #endif
  // keypad handling: get key states from hardware and process them
  keypad_loop();
  // process IR receiver, if activated
  if (get_irReceiverEnabled()) {
    infraredReceiver_loop();
  }
  // update LVGL UI
  gui_loop();
  // call mqtt loop to receive mqtt messages, if you are subscribed to some topics
  #if (ENABLE_WIFI_AND_MQTT == 1)
  mqtt_loop();
  #endif

  // --- every 100 ms -------------------------------------------------------------------
  // Refresh IMU data (motion detection) every 100 ms
  // If no action (key, TFT or motion), then go to sleep
  if(millis() - *pIMUTaskTimer >= 100){
    *pIMUTaskTimer = millis();

    check_activity();

  }

  // --- every 1000 ms ------------------------------------------------------------------
  if(millis() - *pUpdateStatusTimer >= 1000) {
    *pUpdateStatusTimer = millis();

    // update user_led, battery, BLE, memoryUsage on GUI
    updateHardwareStatusAndShowOnGUI();
  }

}

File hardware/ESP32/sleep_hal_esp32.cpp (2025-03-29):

#include <Arduino.h>
#include "SparkFunLIS3DH.h"
#include "sleep_hal_esp32.h"
// before going to sleep, some tasks have to be done
// save settings
#include "preferencesStorage_hal_esp32.h"
// turn off power of IR receiver
#include "infrared_receiver_hal_esp32.h"
// turn off tft
#include "tft_hal_esp32.h"
// turn off SD card
#include "sd_card_hal_esp32.h"
// disconnect WiFi
#include "mqtt_hal_esp32.h"
// disconnect BLE keyboard
#include "keyboard_ble_hal_esp32.h"
// prepare keypad keys to wakeup
#include "keypad_keys_hal_esp32.h"

#if (OMOTE_HARDWARE_REV >= 5)
  const uint8_t ACC_INT_GPIO = 2;
#else
  const uint8_t ACC_INT_GPIO = 13;
#endif

int DEFAULT_MOTION_THRESHOLD = 80; // motion above threshold keeps device awake
int DEFAULT_SLEEP_TIMEOUT = 20000; // default time until device enters sleep mode in milliseconds. Can be overridden.

// is "lift to wake" enabled
bool wakeupByIMUEnabled = true;
// timeout before going to sleep
uint32_t sleepTimeout;
// threshold for motion detection
uint8_t motionThreshold;
// Timestamp of the last activity. Go to sleep if (millis() - lastActivityTimestamp > sleepTimeout)
uint32_t lastActivityTimestamp;

LIS3DH IMU(I2C_MODE, 0x19);
Wakeup_reasons wakeup_reason;

void setLastActivityTimestamp_HAL() {
  // There was motion, touchpad or key hit.
  // Set the time where this happens.
  lastActivityTimestamp = millis();
}

void activityDetection() {
  // if there is any motion, setLastActivityTimestamp_HAL() is called 
  int motion = 0;
  
  // A variable declared static inside a function is visible only inside that function, exists only once (not created/destroyed for each call) and is permanent. It is in a sense a private global variable.
  static int accXold;
  static int accYold;
  static int accZold;
  int accX = IMU.readFloatAccelX()*1000;
  int accY = IMU.readFloatAccelY()*1000;
  int accZ = IMU.readFloatAccelZ()*1000;

  // determine motion value as da/dt
  motion = (abs(accXold - accX) + abs(accYold - accY) + abs(accZold - accZ));
  // If the motion exceeds the threshold, the lastActivityTimestamp is updated
  if(motion > motionThreshold) {
    // Serial.printf("Motion activity %d at %lu ms\r\n", motion, millis());
    setLastActivityTimestamp_HAL();
  }

  // Store the current acceleration and time 
  accXold = accX;
  accYold = accY;
  accZold = accZ;
}

void configIMUInterruptsBeforeGoingToSleep()
{
  uint8_t dataToWrite = 0;

  //LIS3DH_INT1_CFG   
  //dataToWrite |= 0x80;//AOI, 0 = OR 1 = AND
  //dataToWrite |= 0x40;//6D, 0 = interrupt source, 1 = 6 direction source
  //Set these to enable individual axes of generation source (or direction)
  // -- high and low are used generically
  dataToWrite |= 0x20;//Z high
  //dataToWrite |= 0x10;//Z low
  dataToWrite |= 0x08;//Y high
  //dataToWrite |= 0x04;//Y low
  dataToWrite |= 0x02;//X high
  //dataToWrite |= 0x01;//X low
  if (wakeupByIMUEnabled) {
    IMU.writeRegister(LIS3DH_INT1_CFG, 0b00101010);
  } else {
    IMU.writeRegister(LIS3DH_INT1_CFG, 0b00000000);
  }
  
  //LIS3DH_INT1_THS   
  dataToWrite = 0;
  //Provide 7 bit value, 0x7F always equals max range by accelRange setting
  dataToWrite |= 0x45;
  IMU.writeRegister(LIS3DH_INT1_THS, dataToWrite);
  
  //LIS3DH_INT1_DURATION  
  dataToWrite = 0;
  //minimum duration of the interrupt
  //LSB equals 1/(sample rate)
  dataToWrite |= 0x00; // 1 * 1/50 s = 20ms
  IMU.writeRegister(LIS3DH_INT1_DURATION, dataToWrite);
  
  //LIS3DH_CTRL_REG5
  //Int1 latch interrupt and 4D on  int1 (preserve fifo en)
  IMU.readRegister(&dataToWrite, LIS3DH_CTRL_REG5);
  dataToWrite &= 0xF3; //Clear bits of interest
  dataToWrite |= 0x08; //Latch interrupt (Cleared by reading int1_src)
  //dataToWrite |= 0x04; //Pipe 4D detection from 6D recognition to int1?
  IMU.writeRegister(LIS3DH_CTRL_REG5, dataToWrite);

  //LIS3DH_CTRL_REG5
  //Set interrupt polarity 
  #if(OMOTE_HARDWARE_REV >= 5)
  IMU.writeRegister(LIS3DH_CTRL_REG6, 0x02); // For active-low interrupt
  #else
  IMU.writeRegister(LIS3DH_CTRL_REG6, 0x00); // For active-high interrupt
  #endif

  //LIS3DH_CTRL_REG3
  //Choose source for pin 1
  dataToWrite = 0;
  //dataToWrite |= 0x80; //Click detect on pin 1
  dataToWrite |= 0x40; //AOI1 event (Generator 1 interrupt on pin 1)
  dataToWrite |= 0x20; //AOI2 event ()
  //dataToWrite |= 0x10; //Data ready
  //dataToWrite |= 0x04; //FIFO watermark
  //dataToWrite |= 0x02; //FIFO overrun
  IMU.writeRegister(LIS3DH_CTRL_REG3, dataToWrite);
  
}

// Enter Sleep Mode
void enterSleep(){
  // Save settings to internal flash memory
  save_preferences_HAL();

  // Configure IMU
  uint8_t intDataRead;
  // clear interrupt
  IMU.readRegister(&intDataRead, LIS3DH_INT1_SRC);
  configIMUInterruptsBeforeGoingToSleep();
  // really clear interrupt
  IMU.readRegister(&intDataRead, LIS3DH_INT1_SRC);

  #if (ENABLE_WIFI_AND_MQTT == 1)
  // Power down modem
  wifi_shutdown_HAL();
  #endif

  #if (ENABLE_KEYBOARD_BLE == 1)
  keyboardBLE_shutdown_HAL();
  #endif

  // Prepare IO states
  digitalWrite(LCD_DC_GPIO, LOW); // LCD control signals off
  digitalWrite(LCD_CS_GPIO, LOW);
  #if(OMOTE_HARDWARE_REV >= 5)
    digitalWrite(LCD_WR_GPIO, LOW);
    digitalWrite(LCD_RD_GPIO, LOW);
    digitalWrite(LCD_D0_GPIO, LOW);
    digitalWrite(LCD_D1_GPIO, LOW);
    digitalWrite(LCD_D2_GPIO, LOW);
    digitalWrite(LCD_D3_GPIO, LOW);
    digitalWrite(LCD_D4_GPIO, LOW);
    digitalWrite(LCD_D5_GPIO, LOW);
    digitalWrite(LCD_D6_GPIO, LOW);
    digitalWrite(LCD_D7_GPIO, LOW);
  #else
    digitalWrite(LCD_MOSI_GPIO, LOW);
    digitalWrite(LCD_SCK_GPIO, LOW);
  #endif
  digitalWrite(LCD_EN_GPIO, HIGH); // LCD logic off
  digitalWrite(LCD_BL_GPIO, HIGH); // LCD backlight off
  #if(OMOTE_HARDWARE_REV >= 5)
  digitalWrite(SD_EN_GPIO, HIGH); // SD card off
  #endif
  // pinMode(CRG_STAT, INPUT); // Disable Pull-Up
  pinMode(IR_RX_GPIO, INPUT); // force IR receiver pin to INPUT to prevent high current during sleep (additional 60 uA)
  digitalWrite(IR_VCC_GPIO, LOW); // IR Receiver off
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

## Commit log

2023-06-28 Initial Upload
    [Button Grid.stl, Case.stl, Color Button.stl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]
2023-07-08 Removed font dependency
    "Fredoka Light" font no longer needed
    [Remote.kicad_pcb]
2023-07-08 BOM added
    [BOM.csv]
2023-07-08 GERBER files added
    [designators.csv, positions.csv]
2023-07-15 Fixed missing parts in BOM
    R1, R38, R39, R40
    [BOM.csv]
2023-07-15 fixed missing part in BOM
    [BOM.csv]
2023-07-16 BOM fixes
    - part count fixed (#8)
    - J1 added as optional component
    [BOM.csv]
2023-07-31 Lower default SPI Clock
    Lowered the default SPI clock as some displays might show glitches with the SPI frequency set above 40MHz.
2023-08-01 Added missing library components
    Added the missing library symbols, footprints and 3D-models. These are all in a project-specific library called "omoteLib" (#19)
    [280QV10 v5.step, 541325062_colored.step, 82672Heimdall.stp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]
2023-08-16 Fixed silkscreen of C13 and C14 being swapped (#33)
    * Fixed silkscreen of C13 and C14 being swapped
    * Removed imperial measurements
    KiCad seems to have converted some metric measurements automatically, so this commit cleans that up.
    ---------
    [Remote.kicad_pcb]
2023-08-16 Updates gerbers
    Small Silkscreen fix (see https://github.com/CoretechR/OMOTE/pull/33)
2023-09-13 Added alternate bottom case STL file. (#28)
    * Flat bottom (internal) case uploaded - Should help with support removal for non-tuned printer
    * Moved battery hole chamber north. Should help with battery placement.
    * Delete OMOTE-Chunky v1.step
    Step File removed for now.
    * Moved CAD file to a community parts folder.
    * Create README.md
    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
    [Case-Bulky-Bottom.stl]
2023-09-21 small buttons (#41)
    * smal buttons
    * rename folder
    * README.md
    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
    [Button Grid_TPU.stl, Color Button_TPU.stl, Off Button_TPU.stl]
2023-09-27 Update platformio.ini (#43)
    The used CPU has 4MB of flash memory. With the default settings only 1310720 bytes are used for the program
    Current omote with default settings: Flash: [========= ] 85.1% (used 1115225 bytes from 1310720 bytes)
    Using a different partition table will solve this problem.
    As the OTA feature is not needed this partition can be used for the application.
    With this partition table 3145728 bytes are available for the application
    Flash: [==== ] 35.5% (used 1115225 bytes from 3145728 bytes)
2024-02-12 fixed the ESP32 build action
    - Changed include name to fix build actions
    - Removes Changes in this fork from readme
2024-03-10 Add IR codes for Denon AVR (#61)
    Covers all buttons available on the RC-1243
2024-03-12 removed old LVGL Simulator for Visual Studio, replaced by new simulator
    [modules.cfg]
2024-03-16 prevent high current during sleep
    [sleep_hal_esp32.cpp]
2024-03-24 wait only 5 ms instead of 100 ms for LCD driver to power on
2024-04-05 increased timer until scene is activated
2024-04-14 Charging Dock CAD files added
    [Omote Dock USB-C.step, Omote Dock with no opening.step]
2024-04-15 Added Samsung36 IR protocol: modified: Platformio/hardware/ESP32/infrared_sender_hal_esp32.cpp modified: Platformio/hardware/windows_linux/infrared_sender_hal_windows_linux.cpp modified: Platformio/s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
    Added 5 new devices:
    LG TV
    new file: Platformio/src/devices/TV/device_lgTV/device_lgTV.cpp
    new file: Platformio/src/devices/TV/device_lgTV/device_lgTV.h
    LG Soundbar
    new file: Platformio/src/devices/AVreceiver/device_lgsoundbar/device_lgsoundbar.cpp
    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
2024-04-16 introduction of "device_pool"
2024-05-09 allow gui specific key bindings
    [main.cpp]
2024-05-09 add device gui for yamahaAmp
2024-05-25 Hardware Revision 4 Initial Commit
    Changes in hardware:
    - MAX17048 for battery monitoring instead of ESP32 ADC
    - Onboard LiPo protection for overvoltage, undervoltage and overcurrent (DW01A) (issue #53)
    - Testpoints added for critical signals
    - Capacitor on ESP32_EN changed from 100nF to 1uF ( issue #62)
    - Easier to source LiPo charger (TP4056)
    - LiPo charger status input fixed(issue #55)
    Changes in software:
    - MAX17048G added as source for battery stats (enabled by defining board revision 4 in Platformio.ini)
    [280QV10 v5.step, 541325062_colored.step, 82672Heimdall.step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]
2024-05-25 Fixed 5.1k resistor part number
    Thank you Discord user TechnoSwiss!
    [BOM.csv]
2024-06-09 Fallback in case of sleepTimeout is set to 0
2024-06-22 Update from ESP32-BLE-Keyboard library - Fixed MediaKeys releasing on ReleaseAll
2024-06-23 fixed BOM formatting
    [BOM.csv]
2024-07-07 Added BOM and CPL for JLCPCB orders
    - Added ready-made files for ordering PCBAs at JLCPCB
    - Updated the README with a link to the new Wiki about ordering PCBAs
    [BOM with D2.xlsx, BOM.xlsx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]
2024-07-12 added platformio env for hardware test of the PCB
2024-07-12 don't use main_boardtest.cpp in env:esp32
2024-07-12 action for building esp32_testboard
2024-09-28 new device air conditioner
2024-11-02 support of multiple BLE devices
2024-11-09 add WiFi status to GUI threadsafe
2024-12-07 breaking changes in NimBLE-Arduino 2.0.0 https://github.com/h2zero/NimBLE-Arduino/commit/edc66e8b6c992d4992602c091bcee26261aa77d3 https://github.com/h2zero/NimBLE-Arduino/commit/a078d994b43116c8e0740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
2024-12-11 Add a keypad gui to the simulator (#91)
    * Add a keypad gui to the simulator
    This adds a new dependency on the SDL2 Image library.
    It also adds a json parsing header libary to help load in the
    information about the keys which we store in json.
    The lvgl sdl driver does not filter SDL events by window ID so we have
    to grab them with a filter and only pass the ones that aren't from our
    windows.
    I used this tool to draw the keypad collision polygons for future reference:
    https://n-peugnet.github.io/image-map-creator/
    * Relocate the keypad image and mappings
    * Remove include from include_hal_windows_linux.h
    * Add comment about keymap creator tool
    * Use time function fro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
2024-12-11 LG TV add Power ON/OFF and HDMI4 (#92)
2024-12-13 number replaced by define
    [keypad_keys_hal_esp32.cpp]
2024-12-23 Replaced TFT_eSPI with LovyanGFX
    Replaced GFX library in preparation for rev 5. There should be no change in performance with SPI, but a huge improvement when using 8-bit in rev 5.
    Touch is now also handled by Lovyan with more direct harwdare access than the Adafruit library.
    [sleep_hal_esp32.cpp, tft_hal_esp32.cpp]
2024-12-24 Removed driver_name from main_boardtest
2024-12-24 Fixed touchscreen offset
    - added parameters for touchscree input range to _touch_instance
    [tft_hal_esp32.cpp]
2024-12-24 Fixed touch activity not resetting the standby timer
    [tft_hal_esp32.cpp]
2024-12-24 Preparations for Rev5
    - new environment for ESP32-S3
    - mapped pins to new pinout
    - switched to 8-bit LCD interface
2024-12-25 When sending a BLE key, don't start a blocking advertising if no bond exists at all. First let the user pair a device.
2024-12-26 Increased IMU motion threshold
    - increased threshold for keeping the device awake from 50 to 100
    - remove "bus_shared = true" from LovyanGFX config
2025-01-12 fixed interrupt pin polarity -> interrupts work now!
    [sleep_hal_esp32.cpp]
2025-01-19 Optimized TCA8418 for lower sleep current
2025-01-20 REV5 hardware added
    TODO: update production files and BOMs
    [BOM.csv, Omote.kicad_pcb, Omote.kicad_sch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]
2025-01-26 Shared env for esp32 and esp32-s3. Make use of PSRAM and flash for esp32-s3
2025-01-28 Added Rev5 Fabrication Files
    [BOM with D2.xlsx, BOM.csv, BOM.xlsx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]
2025-01-30 Aligned component orientations for JLCPCB
    [CPL.csv]
2025-02-08 keep device awake if key was pressed
2025-02-08 SD card: currently not used, so don't init at startup
2025-02-08 better readability for battery definitions
2025-02-11 replaced LEDC_LOW_SPEED_MODE with LEDC_SPEED_MODE
    [keypad_keys_hal_esp32.cpp]
2025-02-11 board_build.f_flash = 80000000L for esp32 (as it was before)
2025-02-11 changed LEDC_SPEED_MODE to LEDC_LOW_SPEED_MODE for keyboardBrightness (only available for rev>=5)
2025-02-11 Fixed LCSC number for R7/R9
    The LCSC part number for R7 and R9 was wrongly linked to a 5.1 Ohm resistor instead of a 5.1 KiloOhm resistor.
    [BOM with D2.xlsx, BOM.csv, BOM.xlsx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]
2025-02-11 ESP32-S3: use custom partition table and lvgl memory in PSRAM to have plenty!!! of resources
    [noota_16MB_custom.csv]
2025-02-13 Added library table files
    OMOTE-specific symbol and footprint libraries are automatically linked to the KiCad project
2025-02-15 MOSFET circuit adjustment
    - Increased gate resistors from 330Ohm to 1kOhm to lower edge speeds slightly (not absolutely necessary but 1k seems to be a default value for most display eval boards)
    - Set R25 (gate pull-up for backlight) to 10kOhm like all others
    - Removed C14 to reduce load on the ESP32 pin
    [BOM with D2.xlsx, BOM.csv, BOM.xlsx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]
2025-02-22 limit battery percentage to 100
2025-02-25 removed const for BUTTON_PIN_BITMASK
2025-02-25 added const to BUTTON_PIN_BITMASK and SW_1_GPIO to SW_5_GPIO
2025-02-25 for wakeup_reason, replaced old GPIO 13 with ACC_INT_GPIO
    [sleep_hal_esp32.cpp]
2025-02-25 replaced float comparison with integer comparison (thanks, Pete)
    [sleep_hal_esp32.cpp]
2025-03-29 Fixed gerber zip file naming
2025-03-31 wrong use of IR protocol enums
    [infrared_sender_hal_esp32.cpp]
2025-04-05 removed all hardware related stuff
    [280QV10 v5.step, 541325062_colored.step, 82672Heimdall.step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]
